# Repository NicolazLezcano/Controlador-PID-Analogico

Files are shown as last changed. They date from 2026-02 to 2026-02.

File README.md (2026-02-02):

# Controlador PID Analógico: Diseño, Simulación e Implementación

Este repositorio contiene el desarrollo integral de un controlador PID analógico, desde el modelado teórico y la simulación hasta el diseño de PCB y la validación en hardware real.
---

<p align="center">
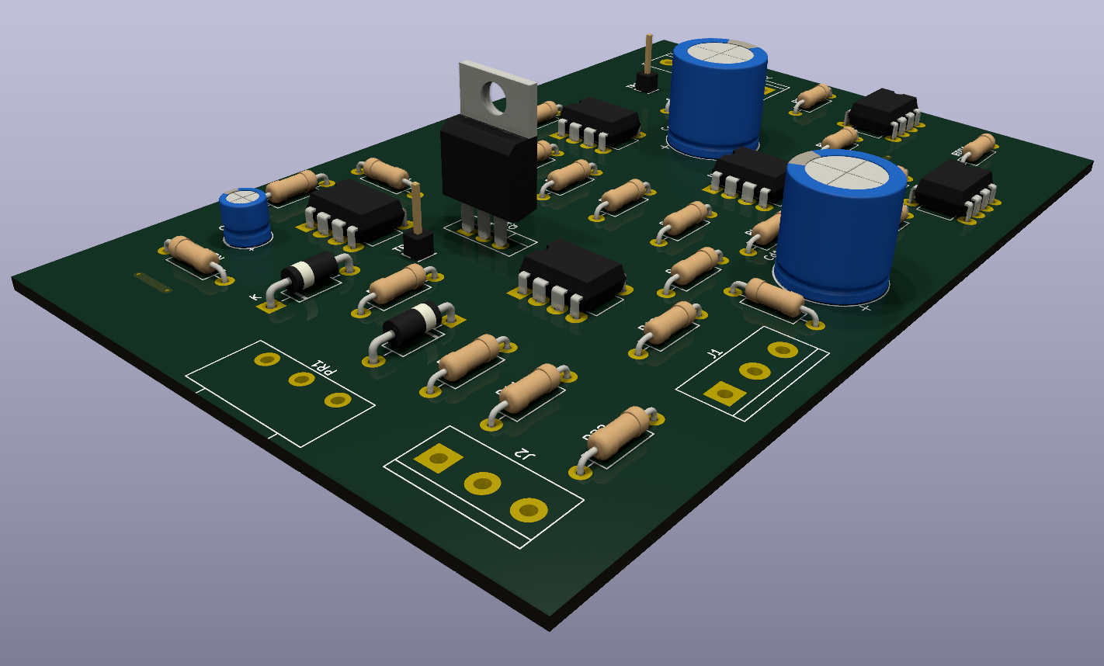
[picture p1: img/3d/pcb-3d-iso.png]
Hero Image
  
</p>

---

## 📋 Características Técnicas
* **Topología:** Controlador PID Analógico.
* **Software de Diseño:** KiCad (v9.0.7).
* **Simulación:** LTspice (v26.0.1).
* **Diseño de PCB:** Single-layer con plano de masa (GND).
* **Documentación:** Informe técnico completo incluido en la carpeta `/docs`.

---

## 📈 Simulación en LTspice
Antes del diseño físico, se validó la respuesta temporal del controlador utilizando **LTspice**. El objetivo fue ajustar las constantes para minimizar el *overshoot* y optimizar el tiempo de establecimiento ($t_s$).

$$u(t) = K_p e(t) + K_i \int_{0}^{t} e(\tau) d\tau + K_d \frac{de(t)}{dt}$$

| Controlador PID | Respuesta al Escalón |
| :---: | :---: |
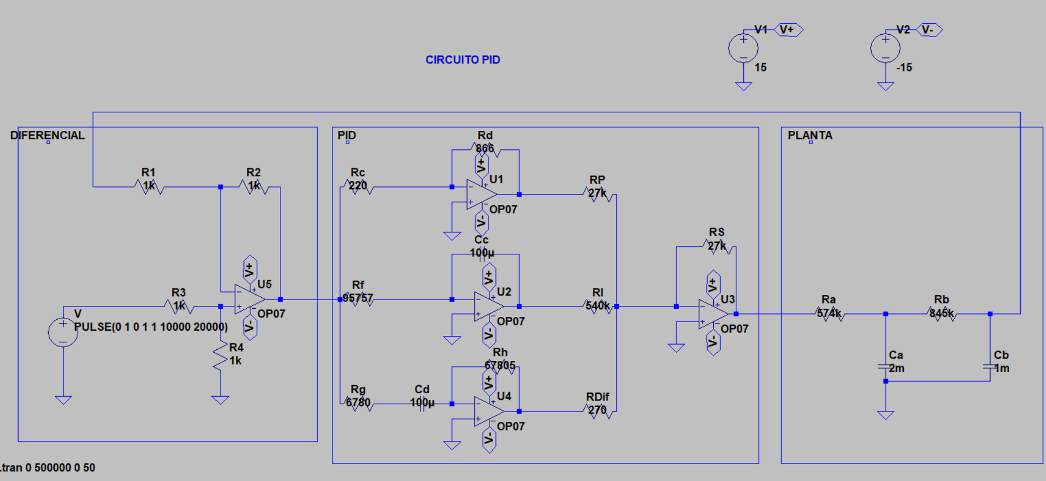
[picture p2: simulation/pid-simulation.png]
Circuito completo del Controlador PID
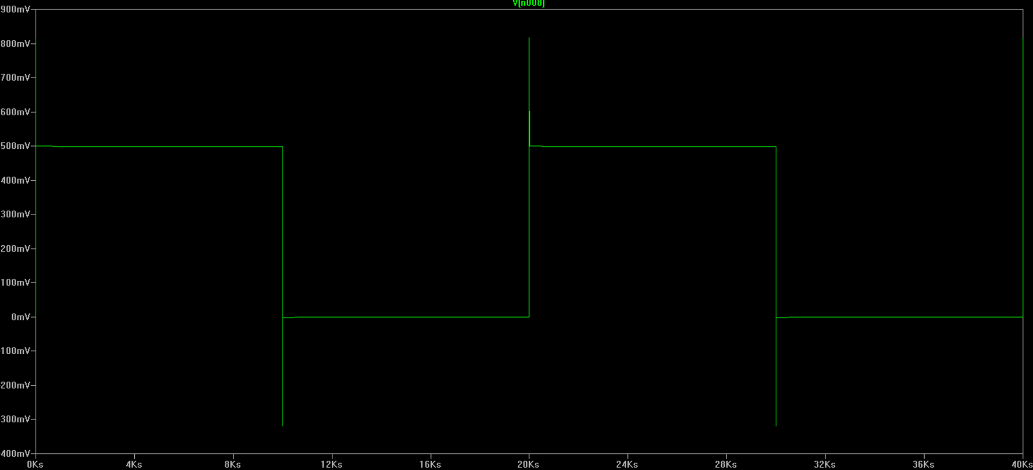
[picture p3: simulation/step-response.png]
Simulación de Respuesta al Escalón
|  |  |

> **Nota:** Los archivos de simulación (`.asc`) están disponibles en la carpeta `/simulation` para su replicación.

---

## 🎨 Diseño de Hardware (KiCad)
El diseño del PCB se optimizó para facilitar el prototipado rápido y garantizar la integridad de la señal frente a ruidos e interferencias.

### Esquemático (Hoja Raíz)
Se utilizó un diseño jerárquico para separar las etapas de adquisición, procesamiento de error y potencia.
<p align="center">
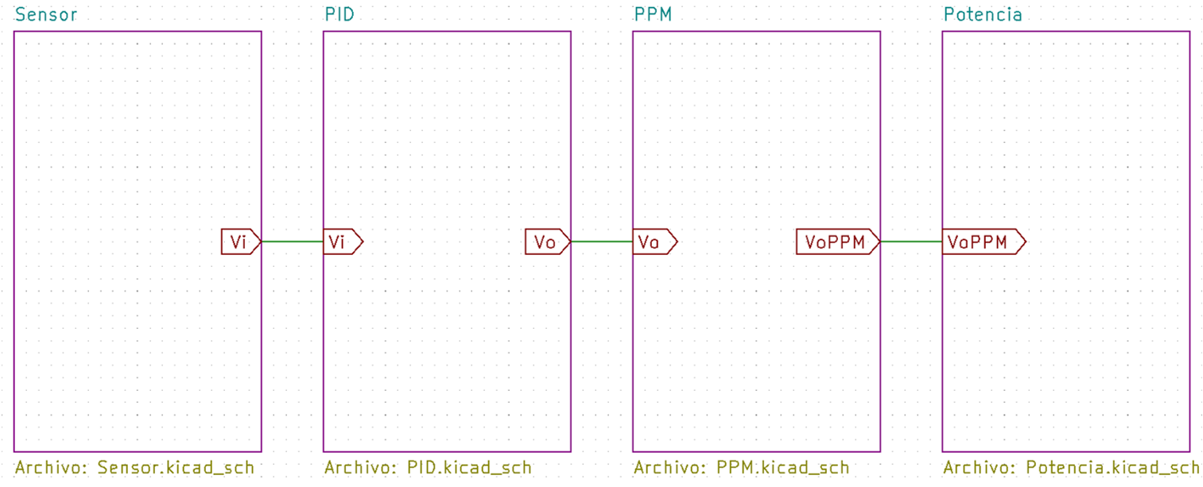
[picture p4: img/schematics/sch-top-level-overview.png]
Esquemático Root
  
</p>

| Sensor | PID |
| :---: | :---: |
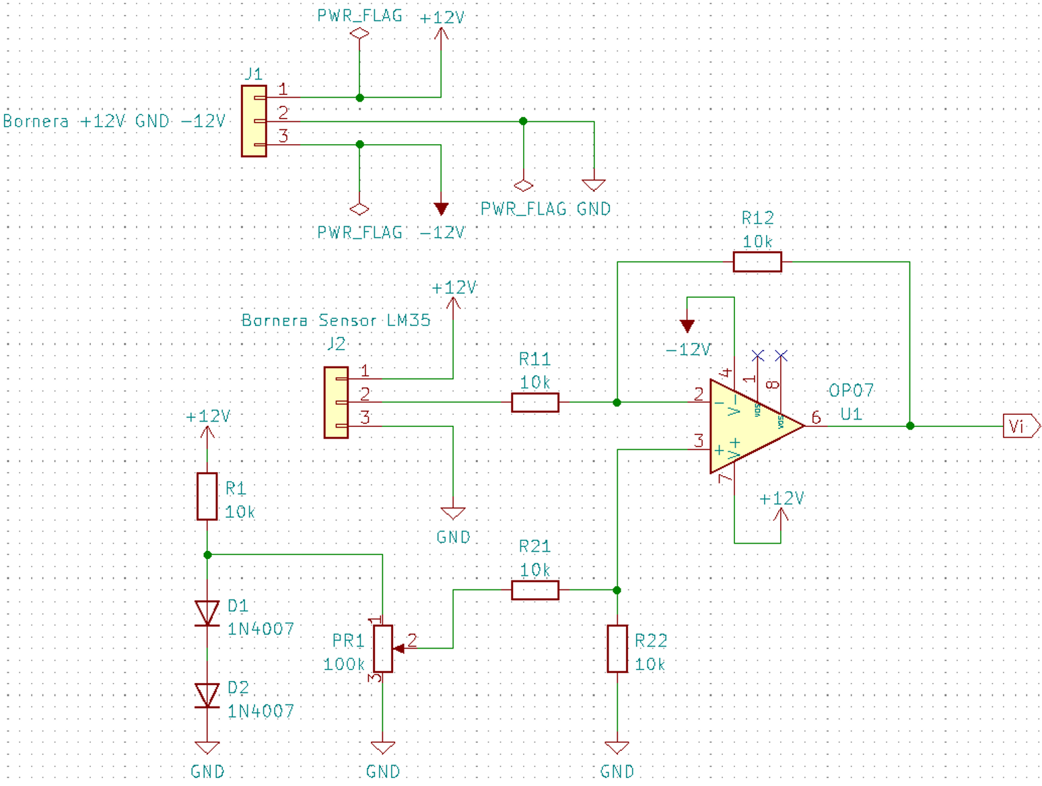
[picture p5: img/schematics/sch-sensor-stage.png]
Esquemático de la etapa de sensado
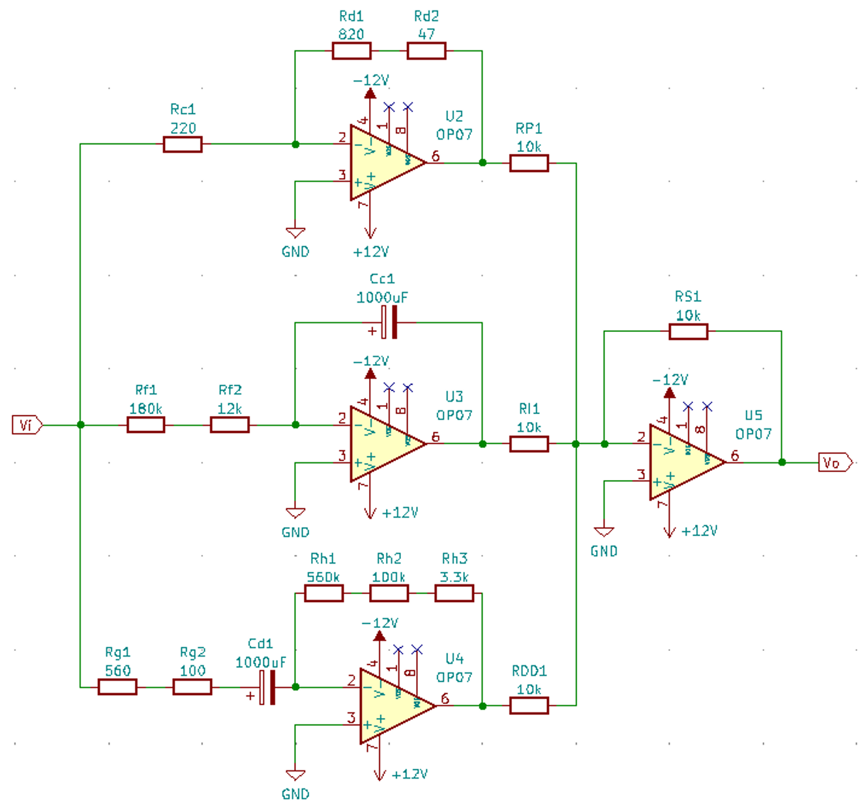
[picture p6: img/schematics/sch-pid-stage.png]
Esquemático del controlador PID
|  |  |

| PPM | Potencia |
| :---: | :---: |
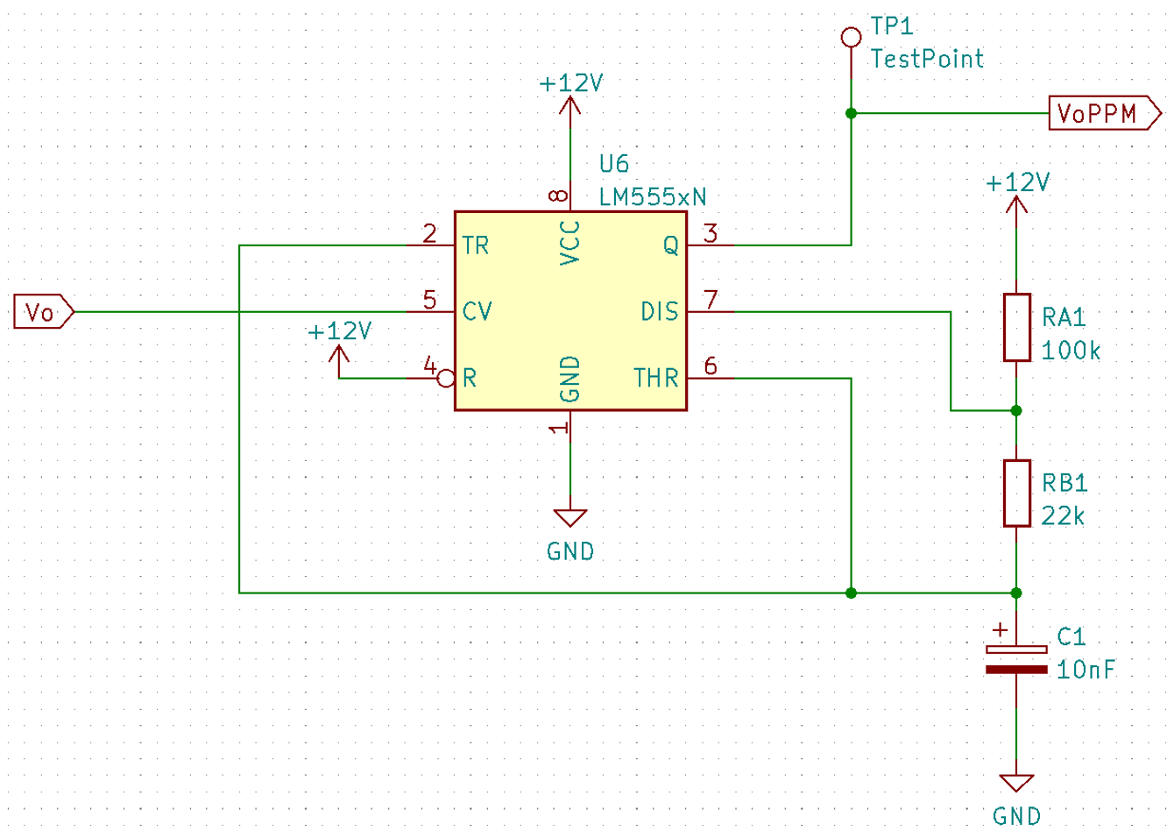
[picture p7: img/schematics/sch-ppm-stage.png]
Esquemático de la etapa PPM
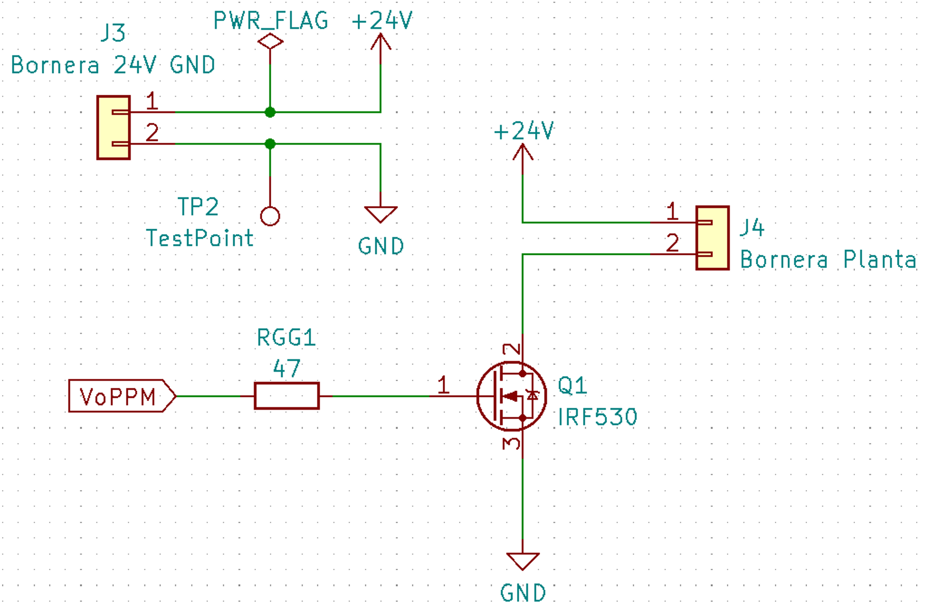
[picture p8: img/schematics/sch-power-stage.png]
Esquemático de la etapa de Potencia
|  |  |

### Layout y Ruteado
* **Integridad de Señal:** Se implementó un plano de masa (**Copper Pour**) para reducir la impedancia de retorno.
* **Single-Layer:** El ruteado se realizó exclusivamente en la capa inferior (**Back Copper**) para simplificar la manufactura manual.

| Ruteado de Pistas (Sin relleno) | Diseño Final (Con Plano de Masa) |
| :---: | :---: |
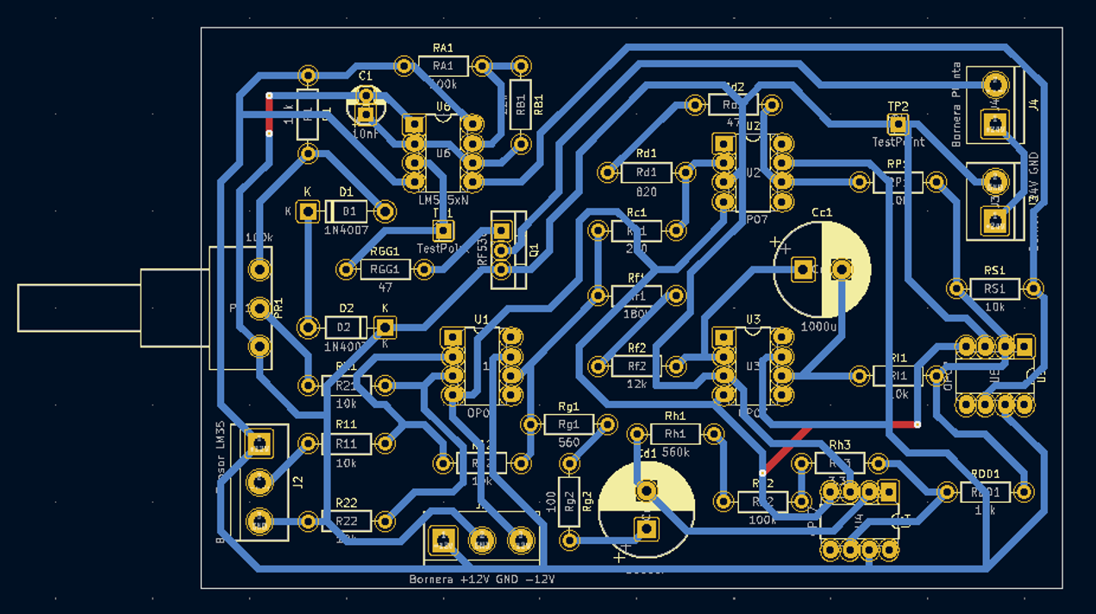
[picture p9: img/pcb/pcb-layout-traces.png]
Traces
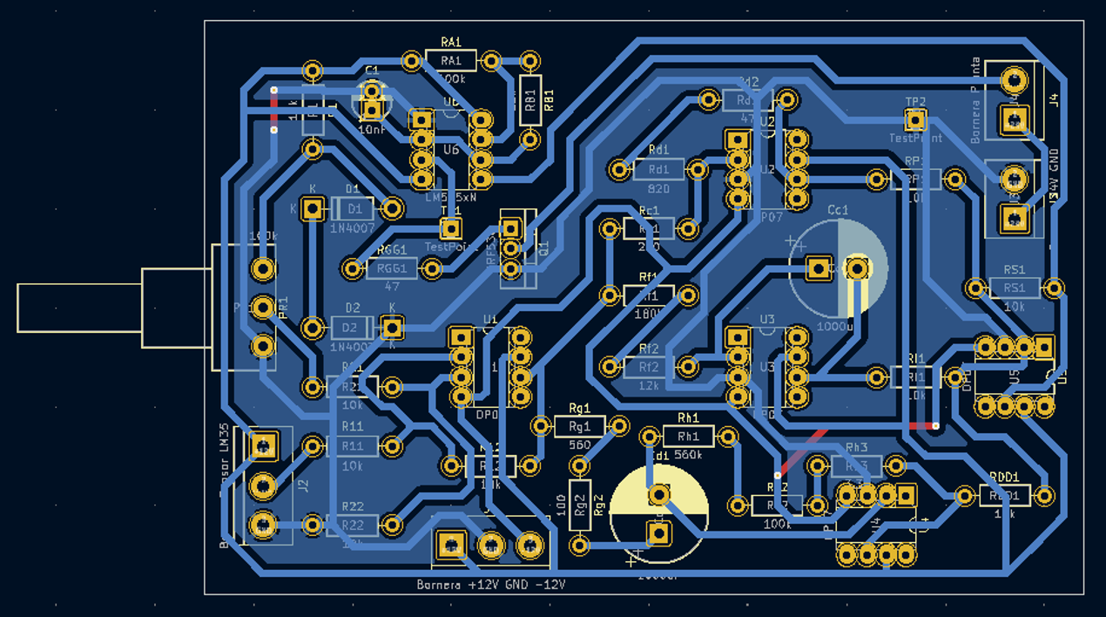
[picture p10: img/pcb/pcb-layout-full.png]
Full
|  |  |

| Modelo 3D (Vista Frontal) | Modelo 3D (Vista Posterior) |
| :---: | :---: |
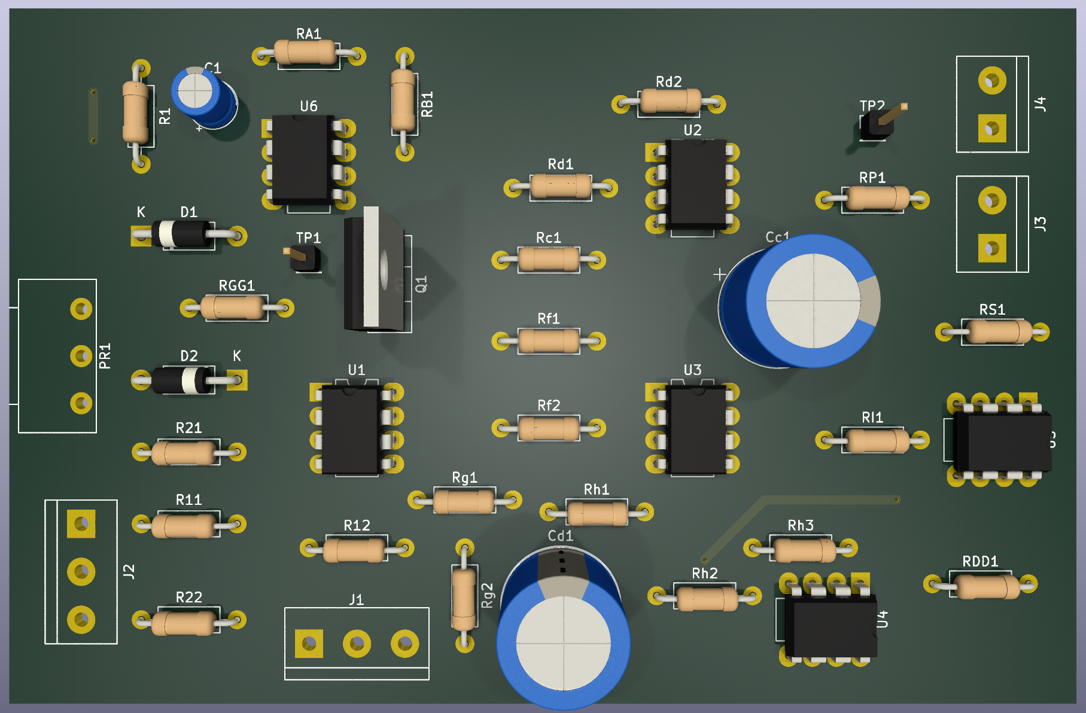
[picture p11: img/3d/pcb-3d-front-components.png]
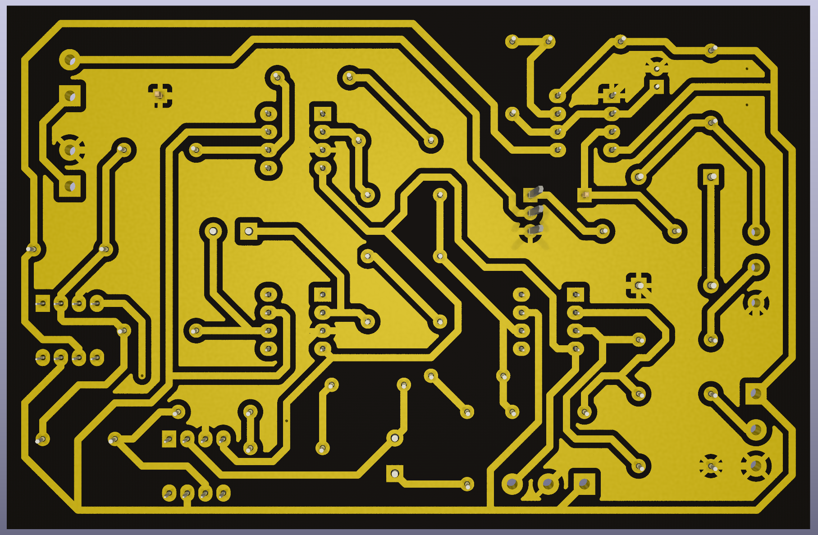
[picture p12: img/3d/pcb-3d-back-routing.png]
|  |  |

---

## 🛠️ Implementación y Resultados Reales
El proyecto concluyó con la fabricación física y la integración con el sensor y la carga, comparando los resultados experimentales con los simulados.

### Montaje y Calidad de Soldadura
| Vista Frontal (Componentes) | Vista Posterior (Soldadura) |
| :---: | :---: |
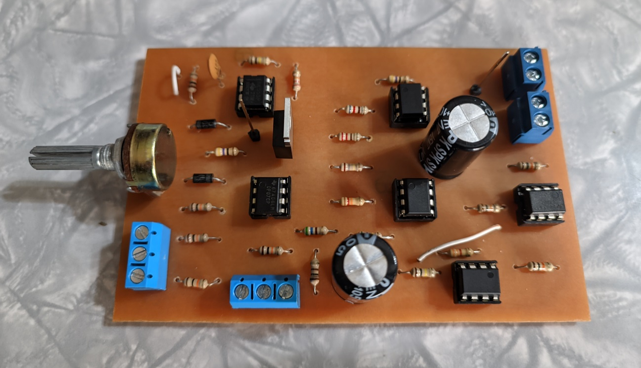
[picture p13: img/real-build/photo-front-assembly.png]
Front Photo
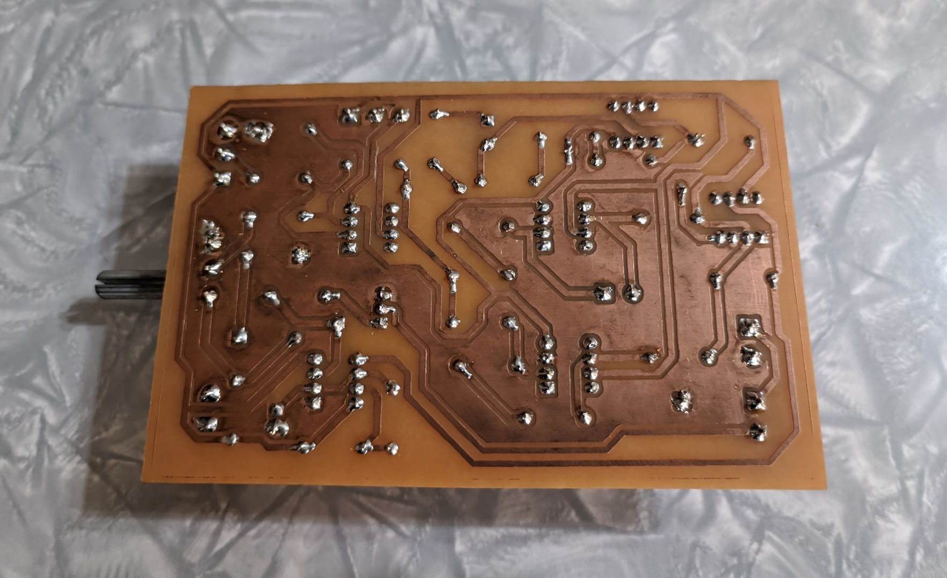
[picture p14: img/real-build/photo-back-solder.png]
Back Photo
|  |  |

### Integración del Sistema
Se validó el lazo cerrado conectando el controlador a la carga (planta térmica) y al sensor de temperatura LM35DZ, verificando la estabilidad del sistema ante perturbaciones.

<p align="center">
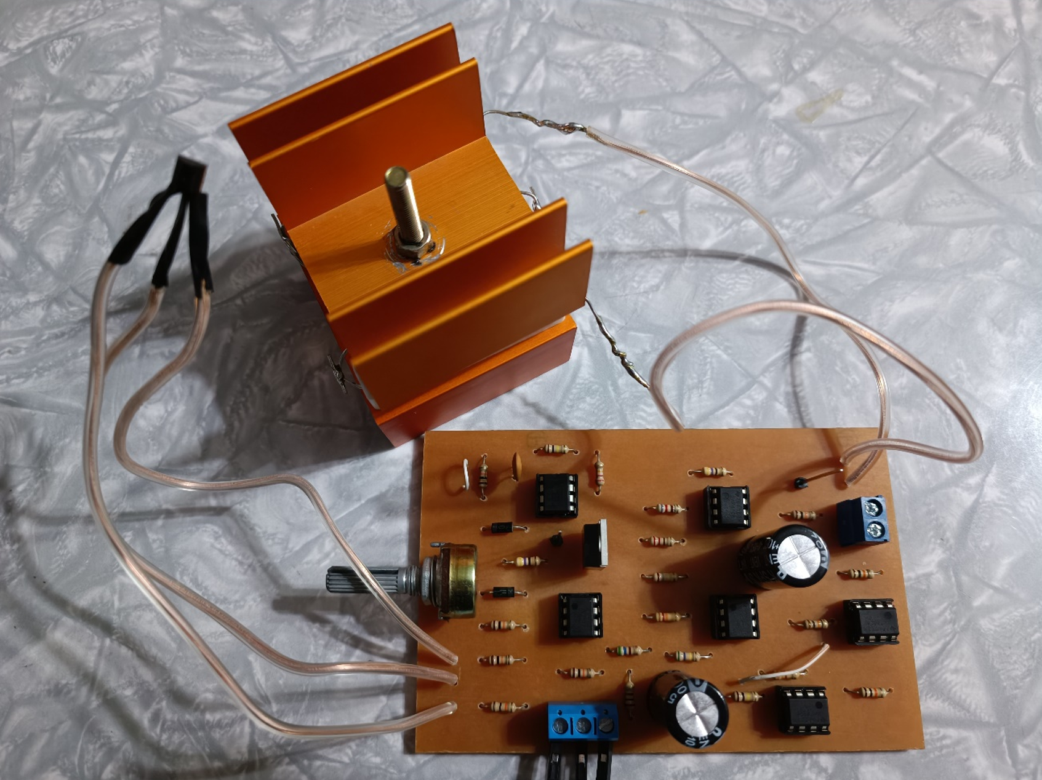
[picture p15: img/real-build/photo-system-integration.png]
Integración Final
  
</p>

---

## 📂 Estructura del Repositorio
* `/kicad`: Archivos fuente del proyecto (`.kicad_pro`, `.kicad_sch`, `.kicad_pcb`).
* `/simulation`: Archivos de LTspice y capturas de ondas.
* `/img`: Imágenes, renders y capturas utilizadas en este README.
* `/docs`: Informe técnico detallado y lista de materiales (BOM).
* `/manufacturing`: Documentación de manufactura dividida en capas (`gerbers/`) y perforaciones (`drill/`). Incluye un archivo .zip listo para servicios de prototipado rápido.

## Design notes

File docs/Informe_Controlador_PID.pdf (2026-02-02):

# Universidad Nacional de La Matanza

# Componentes e Instrumentos de Control

# Informe: Controlador PID

## Alumno: Lezcano Torres, Nicolaz Gastón

## Docentes: Ing. Marsilli, Fernando Roberto Ing. Gómez, Rodrigo Javier

## Código de asignatura: 1057

## Comisión: 01-3900

Componentes e Instrumentos de Control – Informe: Controlador PID

1

Índice:

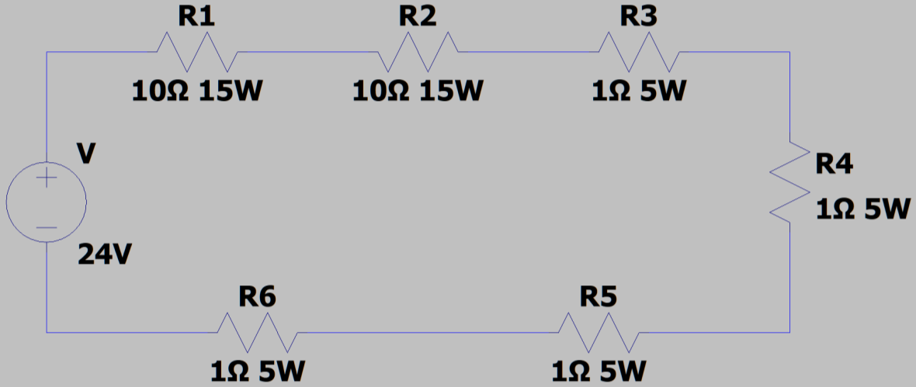
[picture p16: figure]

2

### 1. Planta Térmica

Se tiene una planta térmica, la cual se quiere controlar, la misma está conformada por un conjunto de resistores vinculados a una determinada disipación. Aquí la temperatura aumentará en función de la alimentación que reciban dichos resistores en su respectiva configuración. Además, la temperatura está relacionada a la potencia que genere la planta.

Requerimientos de la Planta: RTOTAL = 24Ω y PTOTAL = 24W =>

PTOTAL =

V

2

RTOTAL

=> V = √PTOTAL . RTOTAL = √24W . 24Ω => V = 24V

PTOTAL = V .I => I =

PTOTAL
V

=

24W
24V

=> I = 1A

Se utilizaron dos resistores cerámicos cementados de 10Ω 15W y cuatro resistores cerámicos cementados de 1Ω 5W, todo conectado en serie, dando como resultado una planta de 24ohm. Dado que la tensión máxima de alimentación es de 24V, circulará una corriente de 1A y la máxima potencia que obtendremos será de 24W.

Ilustración 1. Circuito de la planta térmica

RTOTAL = R1 + R2 + R3 + R4 + R5 + R6 = 10Ω + 10Ω + 1Ω + 1Ω + 1Ω + 1Ω =>

RTOTAL = 24Ω

PR1,2 = I

2
. R1,2 = 1A

2
. 10Ω => PR1,2 = 10W

PR3,4,5,6 = I

2
. R3,4,5,6 = 1A

2
. 1Ω => PR3,4,5,6 = 1W

PTOTAL = 2 . PR1,2 + 4 . PR3,4,5,6 = 2 . 10W + 4 . 1W => PTOTAL = 24W

Los dos disipadores son de aluminio y del tipo aletas, más en específico, son el modelo ZD-1. Los mismos fueron fijados por medio de un tornillo manteniendo firme el conjunto de resistencias y disipadores.

3

Ilustración 2. Planta térmica

Componentes:
x2 Resistor cerámico cementado 10Ω 15W
x4 Resistor cerámico cementado 1Ω 5W
x2 Disipador ZD-1 con una resistencia térmica: θ=3,5°C/W para 75mm x1 Tornillo y tuerca

### 1.1. Emulación de la Planta

En primer lugar, se alimentó la serie de resistencias para así elevar la temperatura de la planta hasta los 100°C. Luego se desconectó la alimentación y se realizó la medición del descenso de temperatura hasta la temperatura ambiente, de aproximadamente 25°C. La medición se realizó mediante un termómetro digital conectado a una PC, para de esta forma exportar la temperatura medida cada dos segundos.

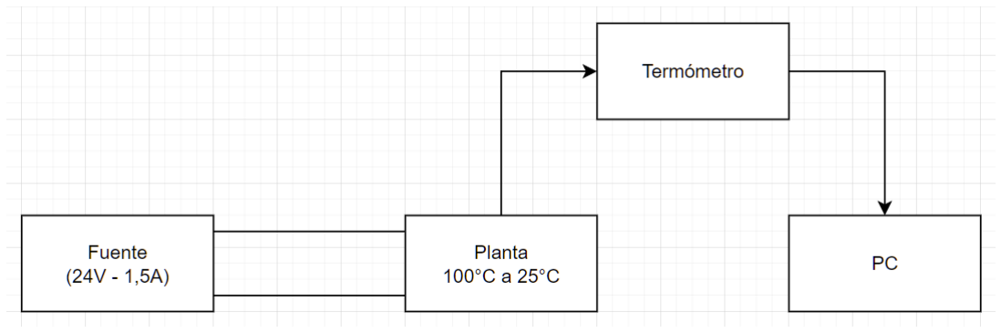
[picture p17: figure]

4

Ilustración 3. Diagrama de conexión para la medición de temperatura

Una planta de segundo orden se puede emular a partir de la siguiente respuesta de la curva, la cual es exponencial decreciente si se cumple que b<0 y d<0:

Curva(t) = a .e

b . t + c .e

d . t

A través de la utilización de MatLab se pueden calcular los coeficientes a, b, c y d. Los valores a ingresar en el software son la parte de la curva que decrece, es decir, cuando la temperatura disminuye a medida que aumenta el tiempo transcurrido, en este caso desde los 100°C hasta la temperatura ambiente, de unos 25°C.

Los exponentes b y d tienen que ser negativos, ya que de lo contrario se obtendría la suma de dos exponenciales crecientes, por lo tanto, se produciría una respuesta inestable. Dicho de otra manera, si los coeficientes b o d son positivos esto quiere decir que hay por lo menos un polo en el semiplano positivo (σ>0), lo que hace que el sistema sea inestable. En un principio, al calcular dichos exponentes se obtenía un valor de d positivo, lo cual es erróneo porque se genera un tipo de respuesta no deseada. Para solucionar este inconveniente se procedió a recortar la muestra por ambos extremos, se eliminaron valores repetidos y una de las acciones más importantes, se eliminaron partes de la muestra en donde la temperatura aumentaba con el paso del tiempo en vez de disminuir, ya que de lo contrario se agrega a la muestra una parte exponencial creciente que provoca la existencia de un valor de d positivo y la inestabilidad en la respuesta.

Las variables tiempo y temperatura, cuya muestra se tomó cada dos segundos, se ingresaron en MatLab como una matriz de 1 columna y 620 filas, ya que de otra forma el software no lo aceptaba.

Ilustración 4. Ingreso de datos en MatLab

Con MatLab se puede obtener el resultado de la suma de dos exponenciales. Estas exponenciales permiten emular una planta de segundo orden. La función a utilizar es la siguiente:

regresion = fit(tiempo,temperatura, ′exp2′)

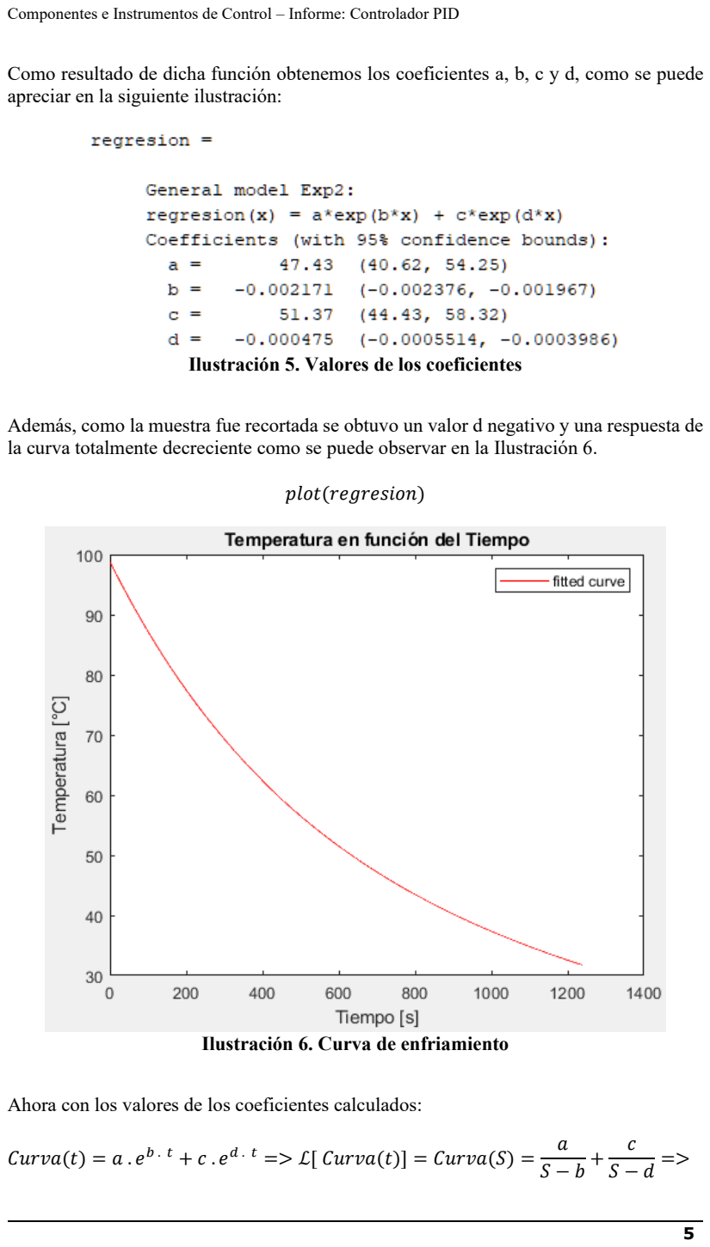
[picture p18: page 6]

5

Como resultado de dicha función obtenemos los coeficientes a, b, c y d, como se puede apreciar en la siguiente ilustración:

Ilustración 5. Valores de los coeficientes

Además, como la muestra fue recortada se obtuvo un valor d negativo y una respuesta de la curva totalmente decreciente como se puede observar en la Ilustración 6.

plot(regresion)

Ilustración 6. Curva de enfriamiento

Ahora con los valores de los coeficientes calculados:

Curva(t) = a .e

b . t + c .e

d . t => ℒ[ Curva(t)] = Curva(S) =

a
S − b

+

c
S − d

=>

6

Curva(S) =

a . (S − d) + c . (S − b)
(S − b) . (S − d)

2 Polos reales negativos: p1 = b y p2 = d => Respuesta Sobreamortiguada

Como |d| = 0,000475 << |b| = 0,002171 => d es el polo dominante

El tiempo de establecimiento se puede calcular a partir del polo dominate de la planta:

Tiempo de Establecimineto: te = 4 . τ = 4 .

1
|d|

=

4
0,000475 => te = 8421,053 s

De los coeficientes calculados nos interesa los polos obtenidos, entonces se puede plantear la siguiente planta genérica de segundo orden para obtener la función transferencia:

G(S) =

k
(S − b) . (S − d)

=

k
S

2 + (−b − d) . S + b . d

Reemplazando por b=-0,002171 y d=-0,000475:

G(S) =

k
S

2 + 2,646 . 10⁻³. S + 1,031 . 10⁻⁶ =>

G(S) =

k
1
S

2 + 2,646 . 10⁻³. S + 1,031 . 10⁻⁶

1
1,031 . 10⁻⁶
1
1,031 . 10⁻⁶

=>

G(S) =

k
1,031 . 10⁻⁶
0,97 . 10⁶ . S

2 + 2566,44 . S + 1

Como k′ =

k
1,031 . 10⁻⁶ => G(S) =

k′
0,97 . 10⁶ . S

2 + 2566,44 . S + 1

Sí k′ = 1 => G(S) =

1
0, 97 . 106 . S

2 + 2566, 44 . S + 1

(1)

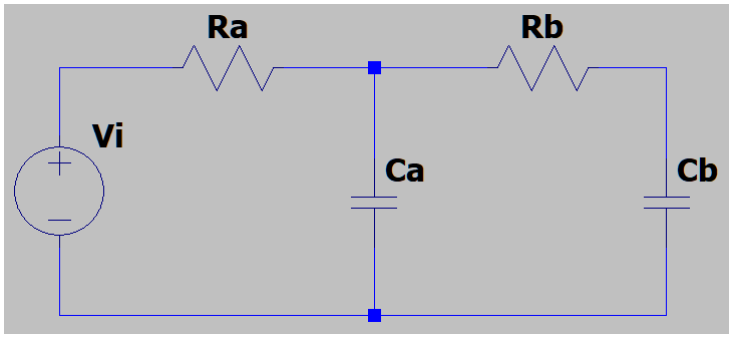
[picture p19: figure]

7

### 1.2. Simulación de la Planta

Ilustración 7. Planta G(S) simulada

Cálculo de G(S) mediante el Método Sistemático de Mallas:

G(S) =

VO(S)
Vi(S)

=

VCb(S)
Vi(S)

=

I2(S) .

1
S . Cb
Vi(S)

I2(S) =

ΔI2
ΔZ =
Ra +

1
S . Ca

Vi(S)

−

1
S . Ca

0

Ra +

1
S . Ca

−

1
S . Ca

−

1
S . Ca

Rb +

1
S . Ca

+

1
S . Cb

=>

I2(S) =

Vi(S)
S . Ca
(Ra +

1
S . Ca

) . (Rb +

1
S . Ca

+

1
S . Cb

) − (−

1
S . Ca

) . (−

1
S . Ca

)

=>

I2(S) =

Vi(S)

Ra . Rb . Ca . S + Ra + Rb +

Ra . Ca
Cb

+

1
S . Cb

G(S) =

I2(S)
S . Cb . Vi(S)

=

1
S . Cb . Vi(S)

Vi(S)

Ra . Rb . Ca . S + Ra + Rb +

Ra . Ca
Cb

+

1
S . Cb

8

G(S) =

1
Ra .Rb . Ca . Cb . S

2 + (Ra . Cb + Rb .Cb + Ra . Ca ) . S + 1

(2)

Para obtener los valores de los resistores y capacitores de la simulación igualo (1) con (2):

(1) = (2) => G(S) =

1
0,97 . 10⁶ . S

2 + 2566,44 . S + 1

=

=

1
Ra . Rb . Ca . Cb . S

2 + (Ra . Cb + Rb . Cb + Ra . Ca ) . S + 1

Como tienen el mismo numerador puedo igualar los coeficientes del denominador de ambos miembros:

0,97 . 10⁶ = Ra . Rb . Ca . Cb | (3)
2566,44 = Ra . Cb + Rb . Cb + Ra . Ca | (4)

Reescribiendo la ecuación (3):

Rb =

0,97 . 10⁶
Ra . Ca . Cb

Reemplazando (3) en (4) obtengo la siguiente ecuación cuadrática:

(Ca + Cb

) . Ra

2 − 2566,44 . Ra +

0,97 . 10⁶
Ca

= 0

En primer lugar, se estableció que: Ca = 2mF = 2000uF y Cb = 1mF = 1000uF

Con dichos valores se obtuvo de la ecuación cuadrática: Ra1 = 573,667kΩ y

Ra2 = 281,812kΩ

Reemplazando los anteriores valores de resistencia en la ecuación (3) se obtuvo que:

Rb1 = 845,428kΩ y Rb2 = 1,721MΩ

Se eligió el primer juego de valores, por lo tanto: Ra = Ra1 y Rb = Rb1

Además, se aproximaron dichos valores de resistencia.

9

Los valores de los resistores y los capacitores son los siguientes:

Ra = 574kΩ ; Ca = 2mF = 2000uF

Rb = 845kΩ ; Cb = 1mF = 1000uF

Por último, se recalculó la función transferencia de la planta G(S) utilizando los valores obtenidos y la ecuación (2), dando como resultado:

G(S) =

1
970060 . S

2 + 2567 . S + 1

### 2. Controlador PID Analógico

Para poder controlar la temperatura de la planta, se ha diseñado un controlador PID que obtiene la señal de referencia de un potenciómetro integrado en el circuito, realimentado negativamente por un sensor de temperatura LM35. Las resistencias de la planta harán de actuadores, dado que, al provocar una circulación de corriente, la temperatura aumentará por efecto Joule.

### 2.1. Modelo de la Planta

Para el modelizado, se consideró a la planta como un sistema de segundo orden, siendo la función de transferencia de la siguiente forma:

G(S) =

1
A . S

2 + B . S + 1

Mediante la curva de enfriamiento se obtuvieron los parámetros A y B, y se llegó a la siguiente expresión de la función transferencia de la planta:

G(S) =

1
970000 . S

2 + 2567 . S + 1

A partir de la planta sin realimentación, podemos evaluar su respuesta ante una señal escalón unitario, para de esta forma ver sus características sin un controlador:

Ilustración 8. Diagrama en bloques del sistema

10

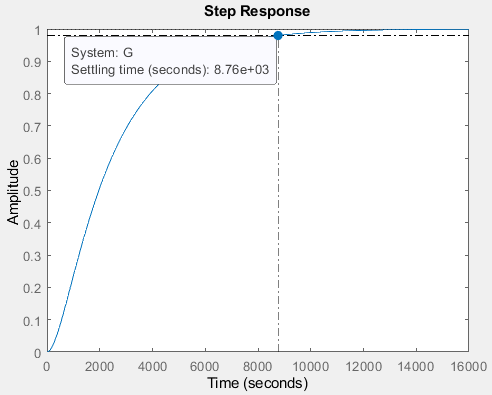
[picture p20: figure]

Ilustración 9. Respuesta al escalón unitario

De la respuesta al escalón unitario de la planta G(S), se obtuvo:

Tiempo de establecimiento: te = 8760 s

### 2.2. Requerimientos de la Respuesta Dinámica

Conociendo los valores de la respuesta sin controlador, se pretende mejorar dichas características, por lo tanto, se establecieron los siguientes requerimientos:

Tiempo de establecimiento: te

′ ≤ 0,75 .te = 0,75 . 8760 s => te

′ ≤ 6570 s

OverSℎoot o Sobreimpulso: MP ≤ 30%

### 2.2.1. Diseño del Controlador PID

Mediante la herramienta SisoTool de MatLab, se procedió a diseñar el controlador. En primer lugar, se cargó la función transferencia y se establecieron los parámetros de la respuesta dinámica requerida. Con esto el sistema nos devuelve una gráfica que nos muestra el lugar de las raíces a lazo cerrado y nos marca automáticamente en el plano complejo la zona donde deben estar ubicados los polos dominantes del sistema para cumplir con los requisitos cargados.

11

El diseño del compensador se realizará a partir del siguiente diagrama, en donde el controlador PID es el bloque C, la planta térmica es el bloque G y la realimentación negativa unitaria es el bloque H:

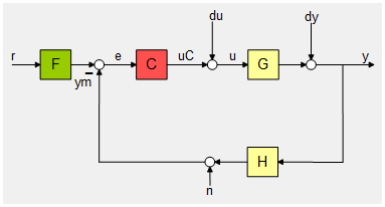
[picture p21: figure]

Ilustración 10. Diagrama en bloques del sistema realimentado

Hecho esto, se agregan los polos y los ceros que le corresponden al controlador PID. Mediante SisoTool podemos visualizar la respuesta al escalón unitario del sistema y al mismo tiempo modificar el Root Locus, para de esta forma probando diferentes alternativas tratar de llegar al objetivo.

En primer lugar, se establecieron los siguientes polos y ceros para el controlador PID, uno de los polos se ubica en el origen ya que cumple la función de ser integrador, además, se utiliza una k=1:

Ilustración 11. Primer ingreso de polos y ceros del controlador

Posteriormente, el polo en el origen se mantiene en el mismo lugar y se acercan los ceros y los polos hacia el origen hasta que los polos dominantes, de color rojo, se encuentren en la zona deseada. Luego de ir probando y moviendo el Root Locus, llegamos a una posición en la que estos se encuentran en la intersección entre la línea vertical correspondiente al tiempo de establecimiento del sistema y las diagonales, correspondientes al OverShoot.

12

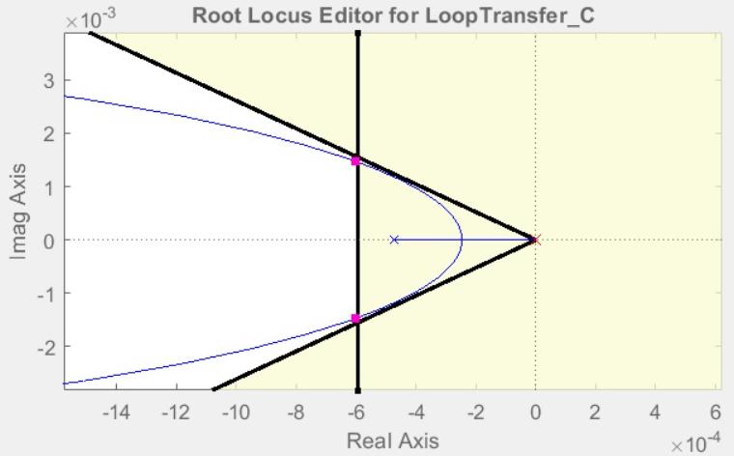
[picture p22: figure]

Ilustración 12. Root Locus de la planta con el controlador y H=1

Finalmente, con esta ubicación de singularidades, podemos ver la respuesta temporal a un escalón del sistema realimentado y con el controlador, verificando que cumpla las especificaciones:

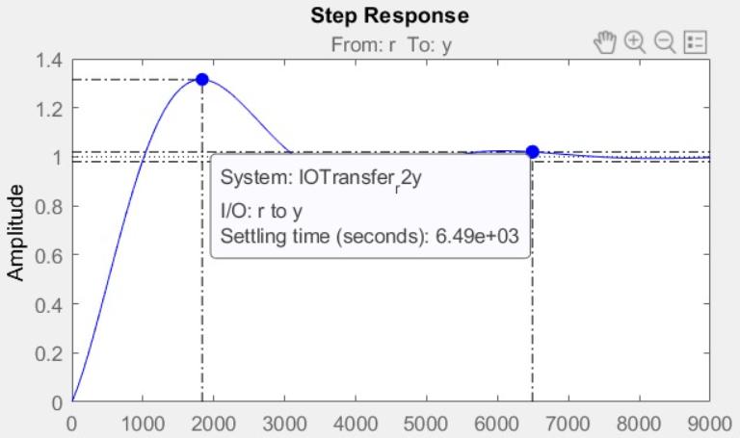
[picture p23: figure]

Ilustración 13. Tiempo de establecimiento de la planta con el controlador y H=1

En este caso se verifica que se cumple con el tiempo de establecimiento estipulado:

te

′ = 6490 s < 6570 s

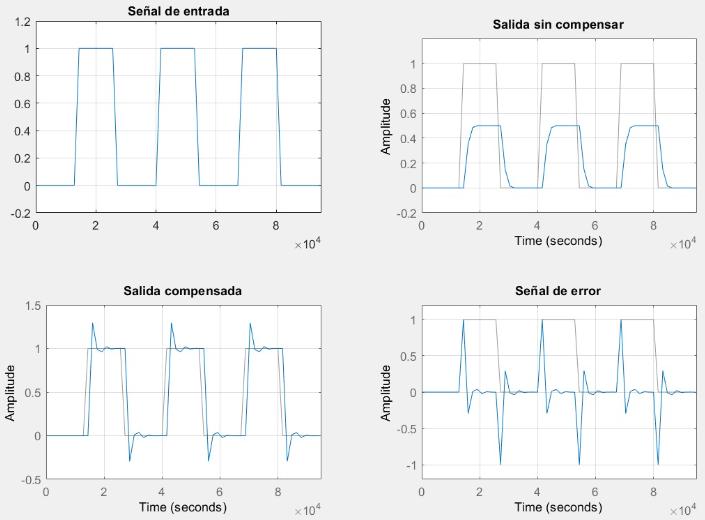
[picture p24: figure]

13

Además, podemos ver frente a una señal cuadrada cómo se comporta el sistema:

Ilustración 14. Señales de entrada, salida y error

La función de transferencia del controlador obtenido mediante SisoTool, es la siguiente:

C(S) =

998,9 . (S + 0,002) . (S + 0,00392) S . (S + 1,5)

=>

C(S) =

998,9 . S

2 + 5,913 . S + 0,007832
S . (S + 1,5)

(5)

### 2.2.1.1. Componentes del Controlador PID

Tenemos que la transferencia del controlador está dada por:

C(s) =

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
2 + (

Rd
RcRgCd

+

1
RfCc

) S +

1
RfRgCcCd
S (S +

1
RgCd

)

(6)

Donde ponemos reescribirla de la siguiente manera:

C(s) =

VO
VI

=

aS

2 + bS + c
S(S + d)

(7)

14

Si a los usamos los resultados obtenidos de Matlab, en la ecuación (5), y los combinamos con la ecuación (6) y (7) nos queda:

Rd
Rc

+

Rℎ
Rg

= a = 998,9 (8)

Rd
RcRgCd

+

1
RfCc

= b = 5,913 (9)

1
RfRgCcCd

= c = 0,007832 (10)

1
RgCd

= d = 1,5 (11)

Además, podemos mostrar la ganancia de cada etapa del controlador:

Vo
Vi

(P) = −

Rd
Rc

= −P (12) Etapa proporcional

Vo
Vi

(I) = −

1
RfCC. S

= −

I
S
(13) Etapa integral

Vo
Vi

(D) = −

Rℎ
Rg

. S

1
RgCd

+ S

= −

D. S
pd + S
(14) Etapa derivativa

Nos quedan, entonces, estas ganancias expresadas de la siguiente manera:

I =

c
d

= 0,0052213 (15)

P =

b − I
d

= 3,9385 (16)

D = a − P = 994,9615 (17)

Si usamos estos valores de ganancias y los reemplazamos en las ecuaciones (8), (9), (10) y (11) vamos a obtener valores de componentes muy elevados, obteniendo los siguientes:

Proporcional: Rc = 220Ω Rd = 866Ω

Integral: Rf = 191,52KΩ Cc = 1mF

Derivativo: Rg = 666, 67Ω | Rℎ = 663,31KΩ | Cd = 1mF

15

Utilizando los valores comerciales más próximos nos quedan los siguientes valores de componentes:

Proporcional: Rc = 220Ω y Rd = 820Ω + 47Ω

Integral: Rf = 180kΩ + 12kΩ y Cc = 1000uF

Derivativo: Rg = 560Ω + 100Ω , Rh = 560kΩ + 100kΩ + 3, 3kΩ y Cd = 1000uF

Sumador: RS = RP = RI = RD = 10kΩ

Dado que los valores de los capacitores y de Rh son algo difíciles de conseguir, se usará el sumador para, modificando la ganancia de cada etapa, equilibremos esa modificación y obtengamos valores de componentes más accesibles.

De esta forma, la función de transferencia del PID más el sumador nos queda:

− (−

P. Vi
RP

−

I. Vi
S. RI

−

D. S. Vi
(S + pd

)RD

)Rs = Vo

Vo
Vi = (

P
RP

+

I
S. RI

+

D. S
(S + pd

)RD

) RS

Vo
Vi =

P. RS
RP

+

I. RS
S. RI

+

D. RS

. S
(S + pd

)RD

(18)

El valor de P no es un problema, solo se encarga de establecer el valor de Rd y no tenemos un problema allí. Por eso necesitamos modificar las ganancias I y D a valores más convenientes, aumentado el primero y reduciendo el segundo.

Siendo I

∗ y D

∗
los nuevos valores de I y D

I

∗ = I. kI | D

∗ =

D
kD

La transferencia (18) nos queda de la siguiente manera:

Vo
Vi =

P. RS
RP

+

I

∗
. RS
S. RI

+

D

∗
| . RS

. S
| (S + pd

)RD

(19)

Para que la transferencia obtenida con SisoTool no sea modificada necesitamos cumplir:

P. RS
RP

= α. P

I

∗
. RS
RI

= α.I = α

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
. RS
(S + pd

)RD

= α

D
(S + pd

)

= α

D

∗kD
(S + pd

)

→

RS
RD

= α. kD

De aquí, tenemos que α es la ganancia del sumador y vamos a imponerla como “1”. Continuando, vamos a elegir kI y kD según el siguiente criterio:

kI = 20 | kD = 99 → I

∗ = 0,10443 y D

∗ = 10

Teniendo en cuenta estos valores y reemplazando por I

∗donde tenemos I y D

∗ donde
tenemos D, tenemos que:

I

∗ =

c
d
| =
| 1 RfCc → Rf =

1
I

∗Cc

(20)

P

∗ = P =

b − I

∗
d

=

Rd
Rc

→ Rd = P

∗
. Rc (21)

D

∗ = a − P

∗ =

Rℎ
Rg

→ Rℎ = D

∗
. Rg (22)

b =

Rd
RcRgCd

+

1
RfCc

→ Rg =

Rd
RcCd

RfCc
b. RfCc − 1

(23)

Finalmente, fijando los valores de Cc

, Cd y Rc obtenemos los siguientes resultados:

Proporcional: Rc = 220Ω Rd = 866Ω

Integral: Rf = 95,75kΩ Cc = 100μF

Derivativo: Rg = 6,78kΩ | Rℎ = 67,805kΩ | Cd = 100μF
Sumador: RP = RS = 27kΩ RI = 540kΩ | RD = 270Ω

Utilizando los valores comerciales más próximos nos quedan los siguientes valores de componentes:

Proporcional: Rc = 220Ω y Rd = 820Ω + 47Ω

Integral: Rf = 68kΩ + 27kΩ y Cc = 100μF

Derivativo: Rg = 6, 8 kΩ , Rh = 68kΩ y Cd = 100μF

Sumador: RP = RS = 27kΩ , RI = 180kΩ + 180kΩ + 180kΩ y RD = 270Ω

17

Donde el circuito a aplicar es:

Ilustración 15. Controlador PID modificado

### 3. Etapa de Entrada

Esta etapa del circuito es la encargada de fijar la señal de referencia, medir la señal que se recibe del sensor de temperatura y restar esta última a la primera, obtenido al final la señal de error que será la utilizada como señal de entrada del controlador PID.

e = Tr − Tm

Donde Tr es la señal de referencia y Tm la señal medida.

Les etapa está dada por:

18

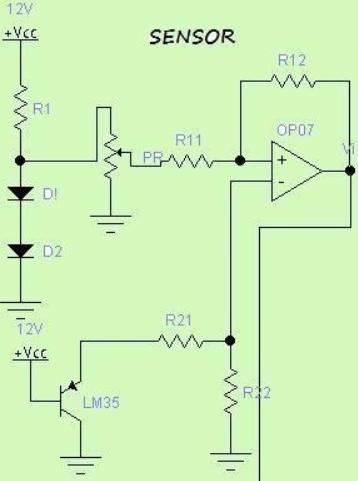
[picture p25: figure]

Ilustración 16. Circuito de sensado

Aquí tenemos que saber que el operacional está funcionando como un restador y R11, R12, R21 y R22 deben ser iguales para cumplir esta función. Los diodos se están encargando de establecer la tensión de entrada al potenciómetro PR.

Dado que vamos a estar usando un LM35 que nos proporcional 10mV/°C y queremos establecer nuestro SetPoint en 100°C, la tensión máxima que nos estará entregando el sensor es de 1V.

Si usamos un potenciómetro de 100k y llamamos Va a la tensión impuesta por los dos diodos y Vb a la tensión que queremos usar de SetPoint (1V), la configuración del potenciómetro tendrá que ser la siguiente:

Ilustración 17. Configuración del potenciómetro

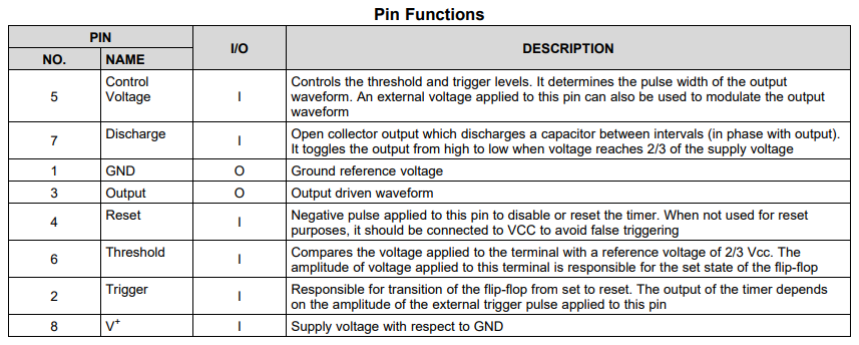
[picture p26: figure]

19

### 4. Etapa PPM y de Potencia

La etapa de potencia consta solamente de un transistor MOSFET, el cual conmutará la alimentación de la serie de resistencias de la planta.

La señal de accionamiento del MOSFET proviene de un modulador de posición de pulso (PPM) que tiene por objetivo variar el tiempo de accionamiento de las resistencias en función de la señal de entrada VO_PID, proveniente de la salida de la etapa PID. El modulador está construido a partir del integrado LM555 configura en modo astable. De esta forma la señal de salida del integrado será un pulso positivo de ancho fijo y amplitud VCC, que, en función de la señal de entrada, se repetirá más o menos seguido.

Del DataSheet necesitamos obtener el tipo de configuración astable:

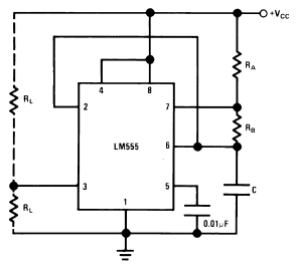
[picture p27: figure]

Ilustración 18. LM555 en modo astable

Y además el nombre de los pines con su descripción:

Ilustración 19. Funciones de los pines del LM555

20

### 4.1. Diseño de la Etapa PPM

La condición de diseño para el oscilador en modo astable es la siguiente:

f = 1kHz

Valiéndonos de las fórmulas que nos brinda la hoja de datos se procederá a calcular los componentes de dicho oscilador:

f =

1,44
(RA + 2 . RB) . C

=> RB =

1,44 − f . RA . C
2 . f . C

(24)

Se establece que: RA = 1kΩ y C = 1μF

Luego, se reemplazan los valores anteriores en la ecuación (24):

RB =

1,44 − 1kHz . 1kΩ . 1μF
2 . 1kHz . 1μF

=> RB = 220Ω

Los valores de componentes para el PPM son:

RA = 1kΩ , RB = 220Ω y C = 1μF

En las especificaciones del LM555 se recomienda que se cumplan las siguientes condiciones:

RA > 5kΩ y RB > 3kΩ

Por lo mencionado anteriormente se procedió a multiplicar por cien los resistores y a dividir por cien a la capacidad, ya que esto no altera la condición de frecuencia solicitada, quedando:

RA = 100kΩ , RB = 22kΩ y C = 10nF

Una vez calculados los valores de los elementos se pueden obtener las características de la forma de onda de salida del PPM:

21

Ilustración 20. Forma de onda del oscilador en modo astable

En este caso como la alimentación de la etapa PPM es de VCC=12V, la amplitud de la señal cuadrada de salida también es de 12V. En la Ilustración 20, en el gráfico de abajo, se puede observar la carga y descarga del capacitor C y los tiempos asociados a dichos procesos.

Amplitud:

A = VCC => A = VOUT = 12V

Tiempo de carga:

t1 = 0,693 . (RA + RB) . C = 0,693 . (100kΩ + 22kΩ) . 10nF => t1 = 0,84546 ms

Tiempo de descarga:

t2 = 0,693 . RB . C = 0,693 . 22kΩ . 10nF => t2 = 0,15246 ms

Período:

T = t1 + t2 = 0,84546 ms + 0,15246 ms => T = 997,92 ms ~1ms

Ciclo de actividad (Duty Cycle):

D =

RA + RB
RA + 2 . RB

=

100kΩ + 22kΩ
100kΩ + 2 . 22kΩ => D = 0,847 = 84,7%

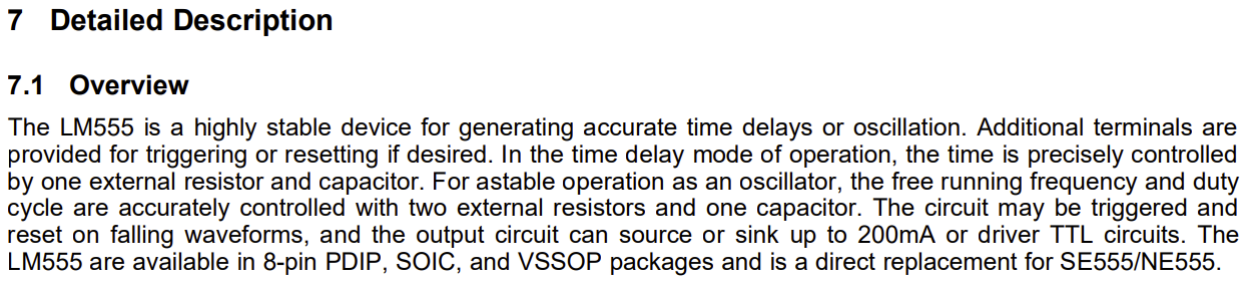
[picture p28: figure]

22

D =

TON

TOFF + TON

=

t1
t2 + t1

=

0,84546 ms
0,15246 ms + 0,84546 ms

=> D = 0,847 = 84,7%

Corroboración de que los valores de componentes obtenidos son correctos:

f =

1
T

=

1
997,92 ms

=> f = 1,0021kHz => f = 1kHz

Por último, una característica muy importante, que hay que tener en cuenta es la corriente de salida del LM555.

Ilustración 21. Corriente de salida del LM555

En el apartado 7.1 de la hoja de datos del LM555 se especifica que la corriente máxima es de 200mA.

IOUT MAX = 200mA

### 4.2. Diseño de la Etapa de Potencia

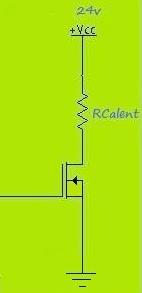
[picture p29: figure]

Ilustración 22. Circuito de la etapa de potencia

El resistor RCalent representa a la planta térmica de 24Ω. A la hora de elegir un transistor MOSFET hay que tener en cuenta algunas condiciones de diseño. La primera es la tensión

23

de ruptura del mismo y la segunda es que la tensión que ingresa al terminal Gate (G) tiene que ser mayor a la tensión VT = VGS(TH)
, que es la diferencia de potencial a partir de la cual el dispositivo empieza a conducir corriente (ID) con una transferencia parabólica.

Se eligió el transistor MOSFET tipo N de canal inducido IRF 530 por la disponibilidad que tiene en el mercado y porque cumple con los requisitos necesarios para ser utilizado en la etapa de potencia. A continuación, se verificará que cumple con las condiciones de diseño.

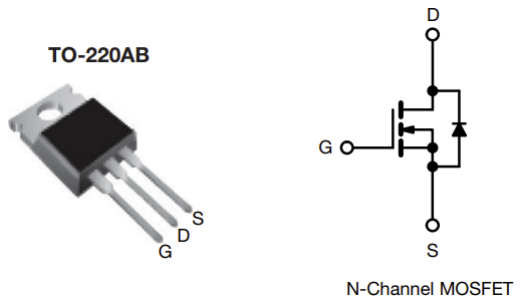
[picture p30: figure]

Ilustración 23. IRF 530 de Vishay

De la hoja de datos del IRF 530 de la marca Fairchild se puede obtener la máxima tensión de operación entre Drain (D) y Source (S) y la tensión a superar para que el MOSFET empiece a conducir:

Ilustración 24. Parámetros del IRF 530 de Fairchild

De la tabla anterior se obtiene que: BVDSS = 100V y VGS(tℎ) = 4V

La etapa de potencia se alimenta con una tensión VCC=24V y al terminal G (gate) del MOSFET le llega una tensión VGS = 12V cuando la salida del LM555 en modo astable de la etapa PPM se encuentra en estado alto, con dichos datos se procederá a confirmar que el IRF 530 cumple los requerimientos necesarios.

Relacionado con la tensión de ruptura del MOSFET se tiene que cumplir que:

VCC ≤ 0,75 . BVDSS = 0,75 . 100V = 75V => VCC ≤ 75V

Se cumple que:
VCC = 24V ≪ 75V

Para que el MOSFET entre en modo de conducción se tiene que cumplir la siguiente condición:

24

VGS > VGS(tℎ) => VGS > 4V

Se cumple que:
VGS = 12V > 4V

Además, el MOSFET IRF 530 tiene una limitación en la tensión VGS que puede soportar:

Ilustración 25. Rango de tensión entre Gate y Source

Como la etapa PPM nos entrega una tensión: 0V ≤ VGS ≤ 12V entonces se puede utilizar el MOSFET IRF 530 sin problemas.

Otra característica muy relevante del MOSFET es la potencia de disipación:

Ilustración 26. Potencia de disipación máxima

Además, la potencia también depende de la temperatura de la carcasa TC:

Ilustración 27. Multiplicador de potencia de disipación en función de Tc

Del gráfico anterior se llegan a los siguientes valores de potencia de disipación según la temperatura:

Cuando TC = 25°C => PDmax = 79W

Cuando TC = 100°C => PD = 0,5 . PDmax = 0,5 . 79W => PD = 39,5W

Corriente máxima de Drain (D):

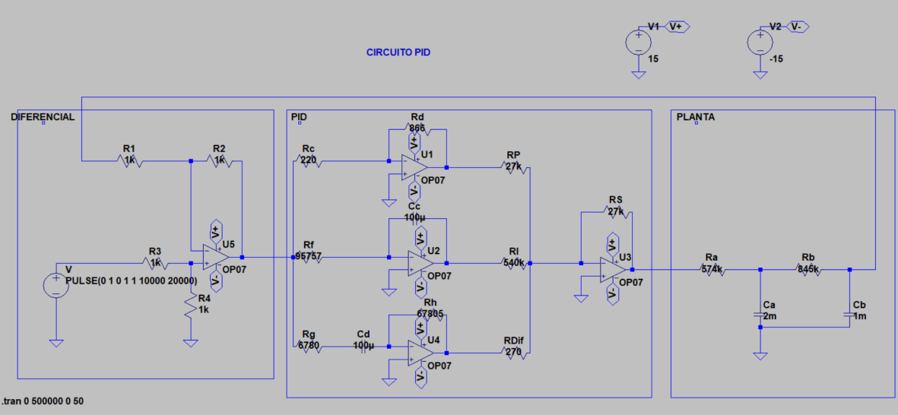
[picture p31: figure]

25

Ilustración 28. Corriente de drenaje

De la Ilustración 27 se obtiene que:

Cuando TC = 25°C => IDmax = 14A

Cuando TC = 100°C => ID = 10A

### 5. Simulación en LTSpice

Colocando los valores de los componentes calculados y hacemos una simulación en el dominio temporal para ver la respuesta del sistema, tenemos:

Ilustración 29. Circuito a simular en LTSpice

Con los siguientes datos cargados para simular:

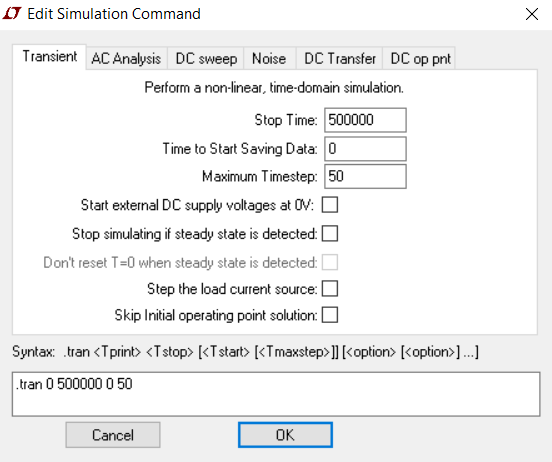
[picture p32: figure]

Ilustración 30. Características de la simulación

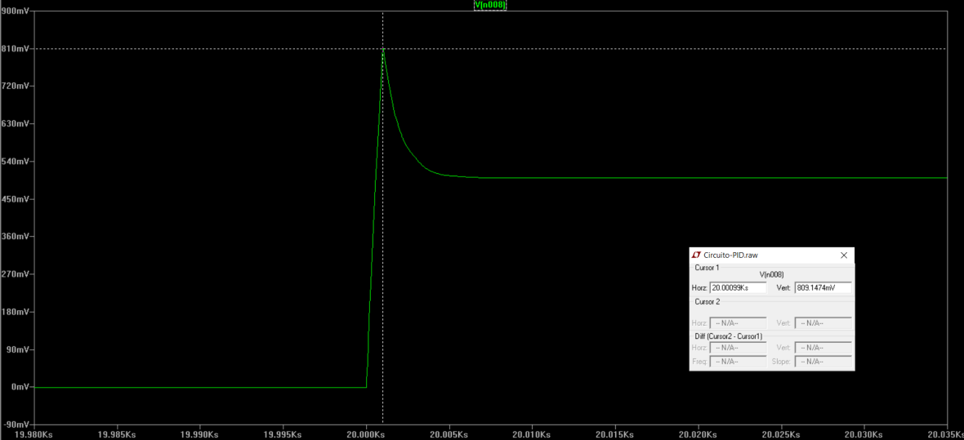
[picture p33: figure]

26

Es fundamental colocar los datos correctos en este panel para obtener una respuesta adecuada, ya que dependerán del tiempo de establecimiento del sistema para que la respuesta de la simulación sea útil.

Finalmente, si miramos la respuesta del sistema en la salida del restador entre la señal cuadrada y la respuesta del PID con controlador obtenemos:

Ilustración 31. Respuesta temporal del sistema controlado

Vemos que obtenemos el mismo resultado que obtuvimos de las simulaciones en MatLab, pero en este caso tenemos un OverShoot algo más grande que lo diseñado:

Ilustración 32. Diferencias en el OverShoot

Haciendo zoom en algún pico de la señal, vemos que tenemos un OverShoot del 60%, lo cual es bastante superior al requerido de 30%. Entendemos que esto se debe a las aproximaciones que realiza el LTSpice comparado con el MatLab y, principalmente, a la simulación de componentes reales no contemplados en el otro programa.

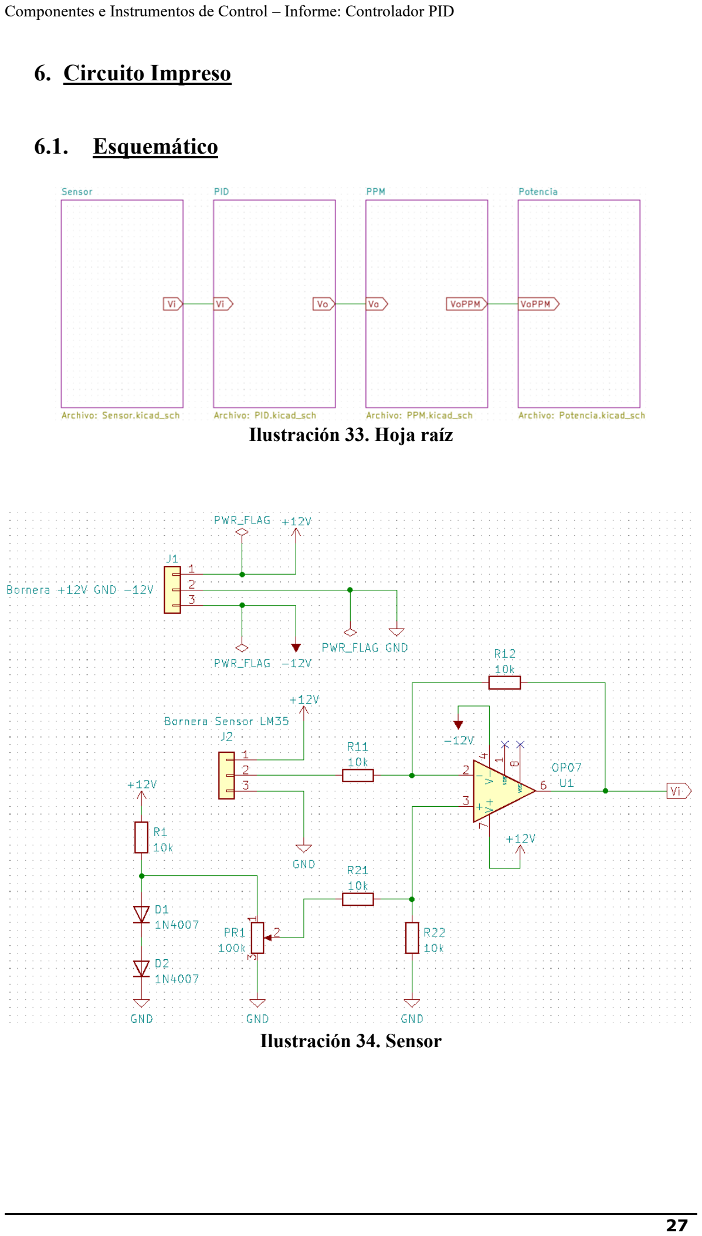
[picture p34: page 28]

27

### 6. Circuito Impreso

### 6.1. Esquemático

Ilustración 33. Hoja raíz

Ilustración 34. Sensor

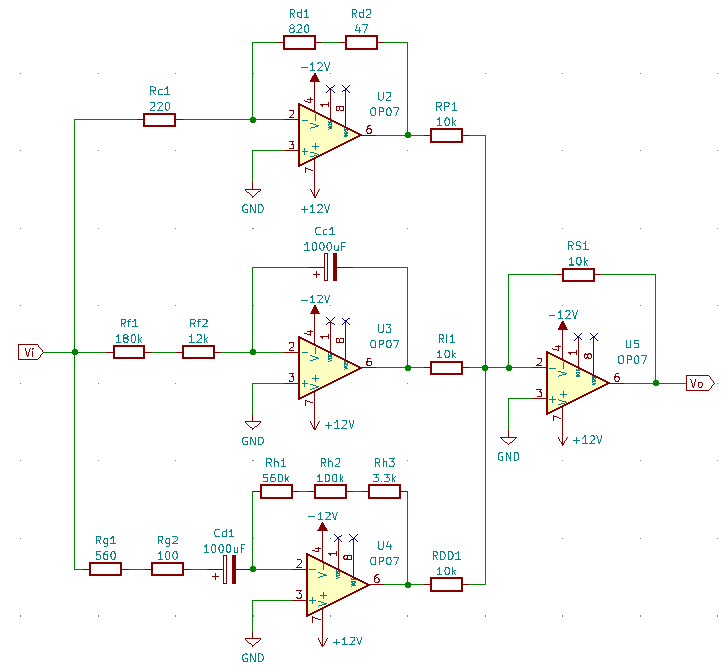
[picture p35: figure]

28

Ilustración 35. PID

29

Ilustración 36. PPM

Ilustración 37. Potencia

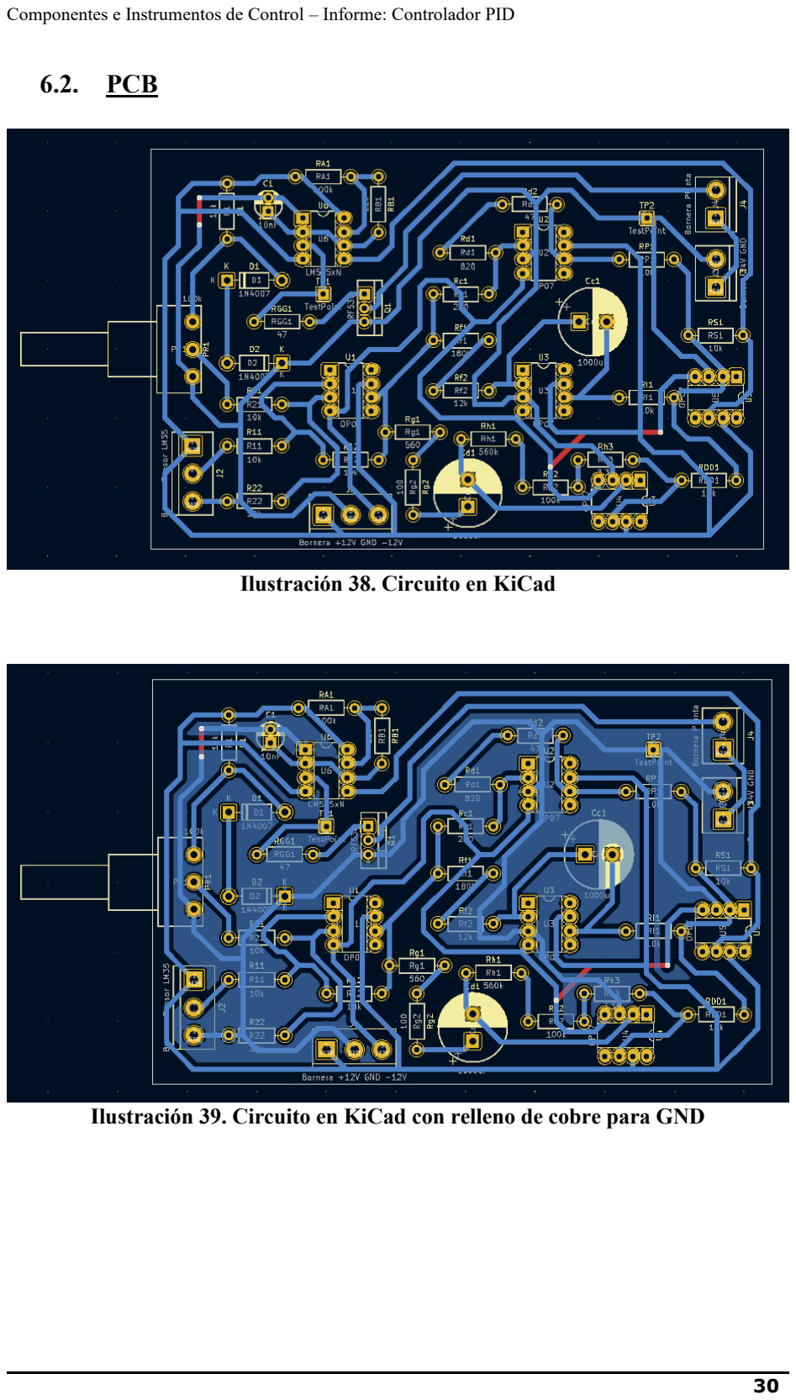
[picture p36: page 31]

30

### 6.2. PCB

Ilustración 38. Circuito en KiCad

Ilustración 39. Circuito en KiCad con relleno de cobre para GND

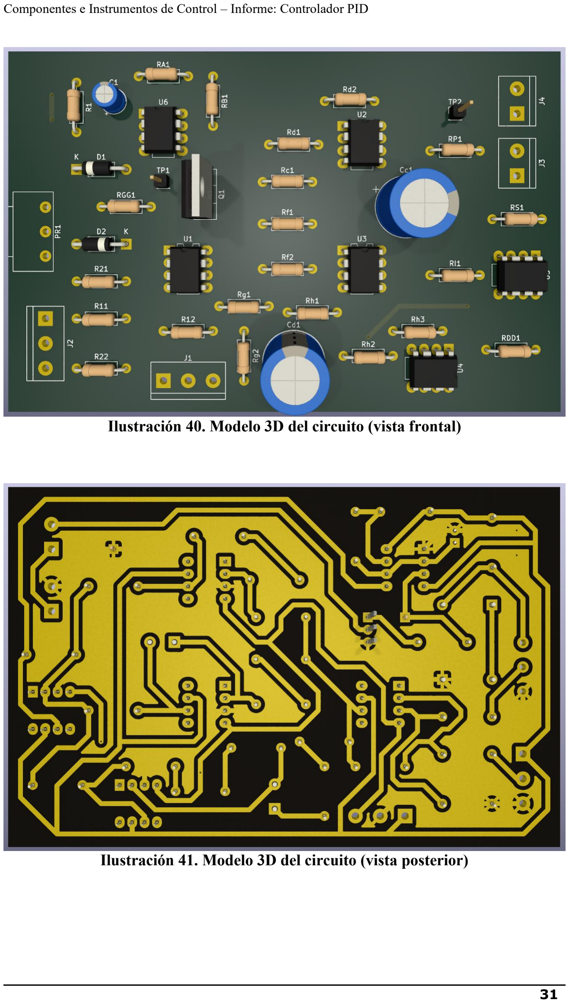
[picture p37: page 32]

31

Ilustración 40. Modelo 3D del circuito (vista frontal)

Ilustración 41. Modelo 3D del circuito (vista posterior)

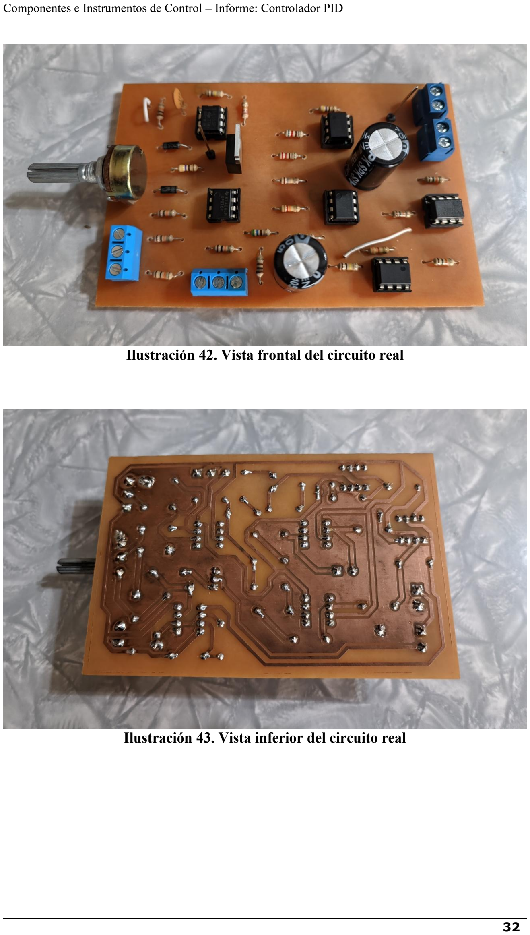
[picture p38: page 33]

32

Ilustración 42. Vista frontal del circuito real

Ilustración 43. Vista inferior del circuito real

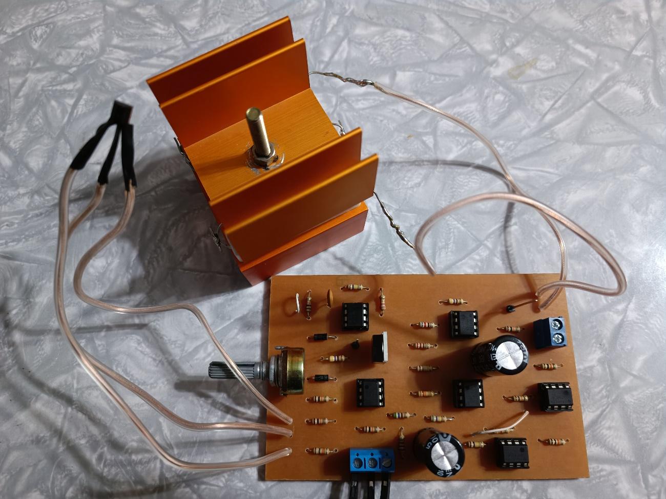
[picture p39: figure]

33

Ilustración 44. Sensor de temperatura LM35DZ, controlador PID y planta térmica

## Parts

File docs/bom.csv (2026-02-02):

Reference | Qty | Value | DNP | Exclude from BOM | Exclude from Board | Footprint | Datasheet
C1 | 1 | 10nF |  |  |  | LibraryNico:CP_Radial_D5.0mm_P2.50mm Nico | ~
Cc1,Cd1 | 2 | 1000uF |  |  |  | Capacitor_THT:CP_Radial_D12.5mm_P5.00mm | ~
D1,D2 | 2 | 1N4007 |  |  |  | Diode_THT:D_DO-41_SOD81_P10.16mm_Horizontal | ~
J1 | 1 | Bornera +12V GND -12V |  |  |  | TerminalBlock:TerminalBlock_bornier-3_P5.08mm | ~
J2 | 1 | Bornera Sensor LM35 |  |  |  | TerminalBlock:TerminalBlock_bornier-3_P5.08mm | ~
J3 | 1 | Bornera 24V GND |  |  |  | TerminalBlock:TerminalBlock_bornier-2_P5.08mm | ~
J4 | 1 | Bornera Planta |  |  |  | TerminalBlock:TerminalBlock_bornier-2_P5.08mm | ~
PR1 | 1 | 100k |  |  |  | Potentiometer_THT:Potentiometer_Piher_PC-16_Single_Horizontal | ~
Q1 | 1 | IRF530 |  |  |  | LibraryNico:TO-220-3_Vertical Nico | http://www.irf.com/product-info/datasheets/data/irf540n.pdf
R1,R11,R12,R21,R22,RDD1,RI1,RP1,RS1 | 9 | 10k |  |  |  | LibraryNico:R_Axial_DIN0207_L6.3mm_D2.5mm_P10.16mm_Horizontal Nico | ~
RA1,Rh2 | 2 | 100k |  |  |  | LibraryNico:R_Axial_DIN0207_L6.3mm_D2.5mm_P10.16mm_Horizontal Nico | ~
RB1 | 1 | 22k |  |  |  | LibraryNico:R_Axial_DIN0207_L6.3mm_D2.5mm_P10.16mm_Horizontal Nico | ~
Rc1 | 1 | 220 |  |  |  | LibraryNico:R_Axial_DIN0207_L6.3mm_D2.5mm_P10.16mm_Horizontal Nico | ~
Rd1 | 1 | 820 |  |  |  | LibraryNico:R_Axial_DIN0207_L6.3mm_D2.5mm_P10.16mm_Horizontal Nico | ~
Rd2,RGG1 | 2 | 47 |  |  |  | LibraryNico:R_Axial_DIN0207_L6.3mm_D2.5mm_P10.16mm_Horizontal Nico | ~
Rf1 | 1 | 180k |  |  |  | LibraryNico:R_Axial_DIN0207_L6.3mm_D2.5mm_P10.16mm_Horizontal Nico | ~
Rf2 | 1 | 12k |  |  |  | LibraryNico:R_Axial_DIN0207_L6.3mm_D2.5mm_P10.16mm_Horizontal Nico | ~
Rg1 | 1 | 560 |  |  |  | LibraryNico:R_Axial_DIN0207_L6.3mm_D2.5mm_P10.16mm_Horizontal Nico | ~
Rg2 | 1 | 100 |  |  |  | LibraryNico:R_Axial_DIN0207_L6.3mm_D2.5mm_P10.16mm_Horizontal Nico | ~
Rh1 | 1 | 560k |  |  |  | LibraryNico:R_Axial_DIN0207_L6.3mm_D2.5mm_P10.16mm_Horizontal Nico | ~
Rh3 | 1 | 3.3k |  |  |  | LibraryNico:R_Axial_DIN0207_L6.3mm_D2.5mm_P10.16mm_Horizontal Nico | ~
TP1,TP2 | 2 | TestPoint |  |  |  | LibraryNico:PinHeader_1x01_P2.54mm_Vertical Nico | ~
U1,U2,U3,U4,U5 | 5 | OP07 |  |  |  | LibraryNico:DIP-8_W7.62mm_LongPads Nico | https://www.analog.com/media/en/technical-documentation/data-sheets/OP07.pdf
U6 | 1 | LM555xN |  |  |  | LibraryNico:DIP-8_W7.62mm_LongPads Nico | http://www.ti.com/lit/ds/symlink/lm555.pdf

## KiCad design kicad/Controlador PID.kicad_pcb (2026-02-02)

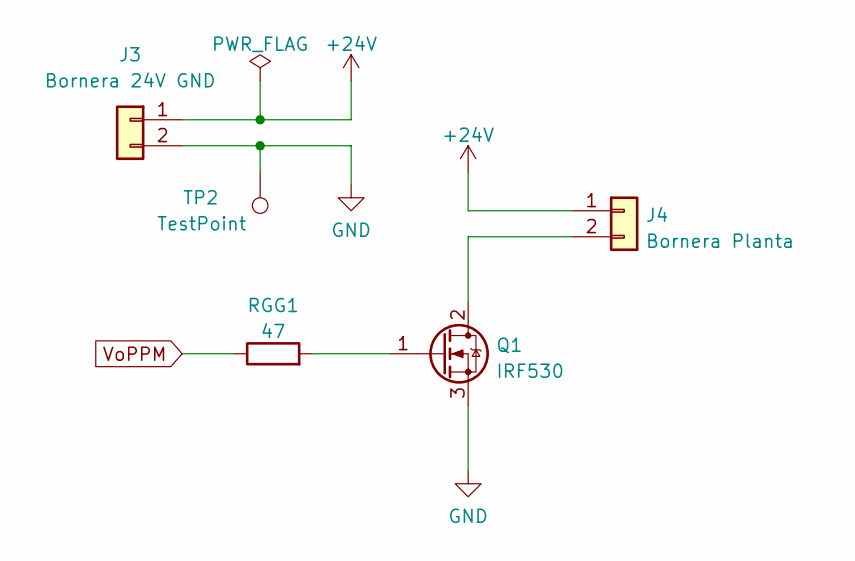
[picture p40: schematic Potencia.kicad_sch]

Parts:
J3: Bornera 24V GND; TerminalBlock_bornier-2_P5.08mm
J4: Bornera Planta; TerminalBlock_bornier-2_P5.08mm
Q1: IRF530; TO-220-3_Vertical Nico
RGG1: 47; R_Axial_DIN0207_L6.3mm_D2.5mm_P10.16mm_Horizontal Nico
TP2: TestPoint; PinHeader_1x01_P2.54mm_Vertical Nico

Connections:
+24V: J3.1, J4.1
GND: J3.2, Q1.3 (S), TP2.1; also elsewhere on the board
unnamed: J4.2, Q1.2 (D)
unnamed: Q1.1 (G), RGG1.2
VoPPM: RGG1.1; also elsewhere on the board

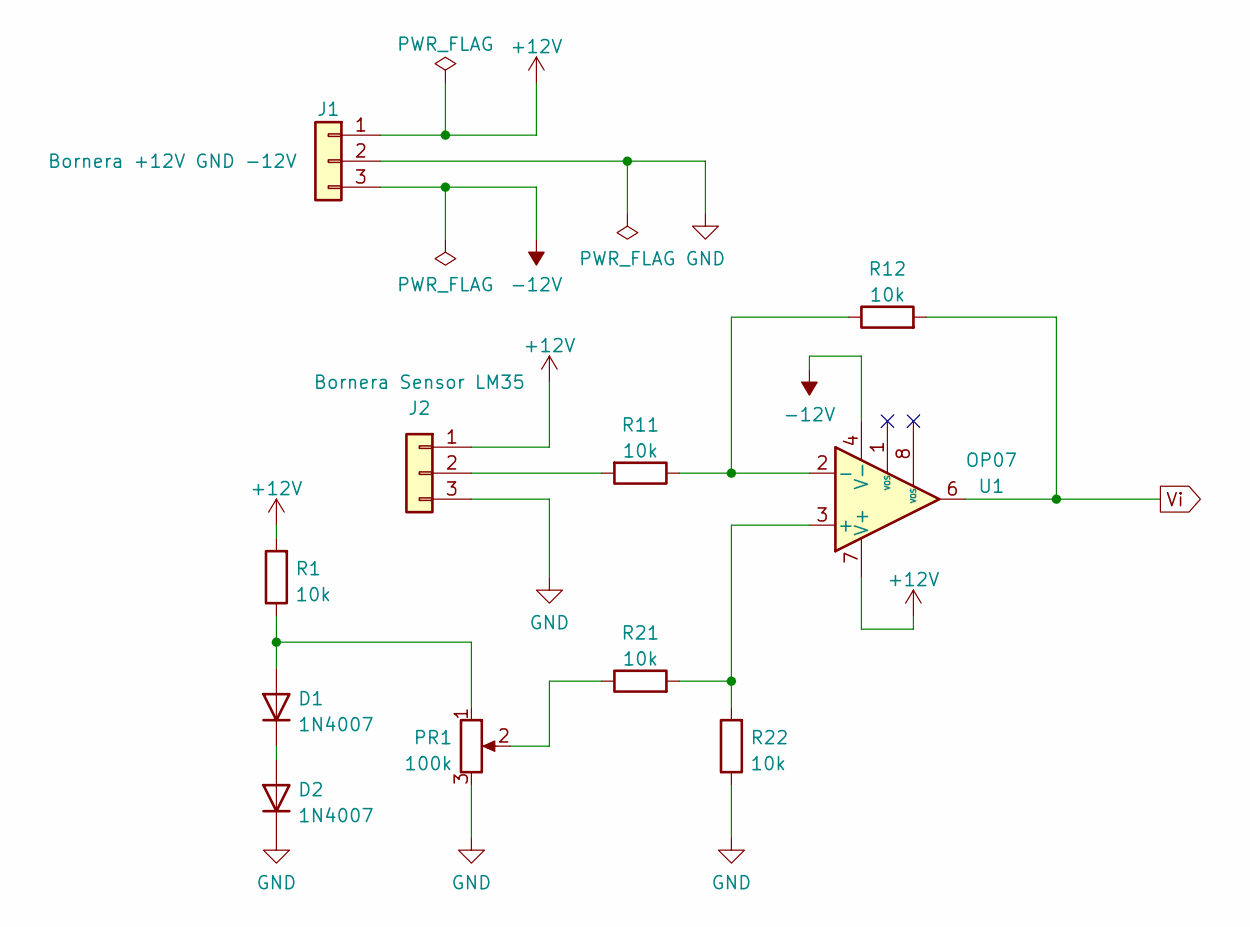
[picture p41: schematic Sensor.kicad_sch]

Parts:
D1, D2: 1N4007; D_DO-41_SOD81_P10.16mm_Horizontal
J1: Bornera +12V GND -12V; TerminalBlock_bornier-3_P5.08mm
J2: Bornera Sensor LM35; TerminalBlock_bornier-3_P5.08mm
PR1: 100k; Potentiometer_Piher_PC-16_Single_Horizontal
R1, R11, R12, R21, R22: 10k; R_Axial_DIN0207_L6.3mm_D2.5mm_P10.16mm_Horizontal Nico
U1: OP07; DIP-8_W7.62mm_LongPads Nico

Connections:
+12V: J1.1, J2.1, R1.2, U1.7 (V+); also elsewhere on the board
-12V: J1.3, U1.4 (V-); also elsewhere on the board
GND: D2.1 (K), J1.2, J2.3, PR1.3, R22.1; also elsewhere on the board
unnamed: D1.1 (K), D2.2 (A)
unnamed: D1.2 (A), PR1.1, R1.1
unnamed: J2.2, R11.2
unnamed: PR1.2, R21.1
unnamed: R11.1, R12.1, U1.2 (-)
unnamed: R21.2, R22.2, U1.3 (+)
Vi: R12.2, U1.6; also elsewhere on the board

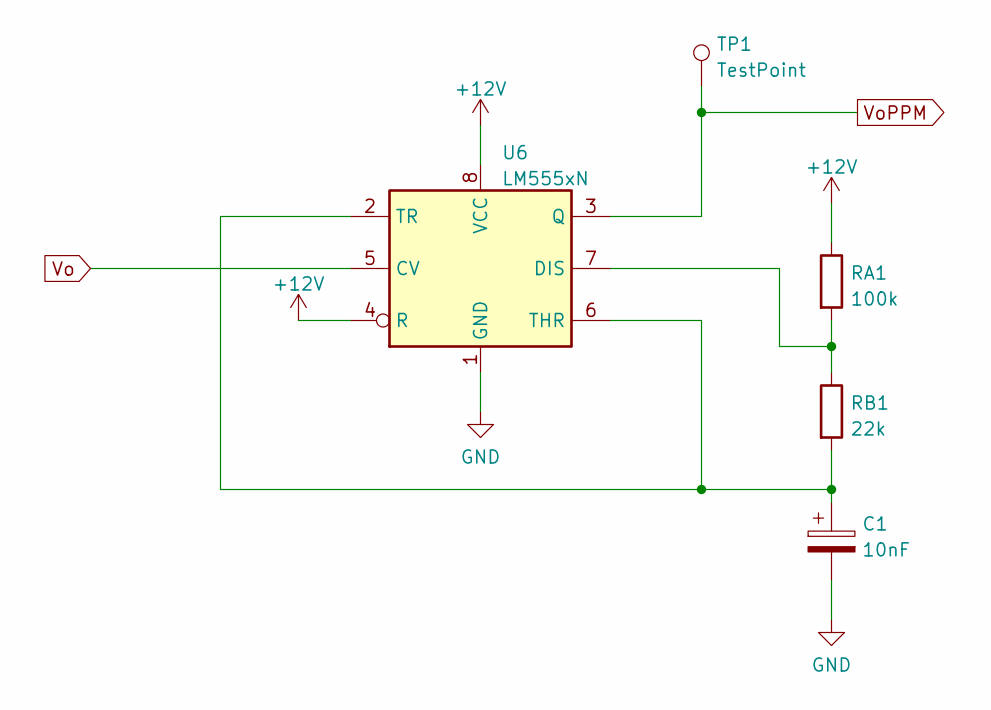
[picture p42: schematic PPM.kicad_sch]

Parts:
C1: 10nF; CP_Radial_D5.0mm_P2.50mm Nico
RA1: 100k; R_Axial_DIN0207_L6.3mm_D2.5mm_P10.16mm_Horizontal Nico
RB1: 22k; R_Axial_DIN0207_L6.3mm_D2.5mm_P10.16mm_Horizontal Nico
TP1: TestPoint; PinHeader_1x01_P2.54mm_Vertical Nico
U6: LM555xN; DIP-8_W7.62mm_LongPads Nico

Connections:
+12V: RA1.1, U6.4 (R), U6.8 (VCC); also elsewhere on the board
GND: C1.2, U6.1 (GND); also elsewhere on the board
unnamed: C1.1, RB1.2, U6.2 (TR), U6.6 (THR)
unnamed: RA1.2, RB1.1, U6.7 (DIS)
Vo: U6.5 (CV); also elsewhere on the board
VoPPM: TP1.1, U6.3 (Q); also elsewhere on the board

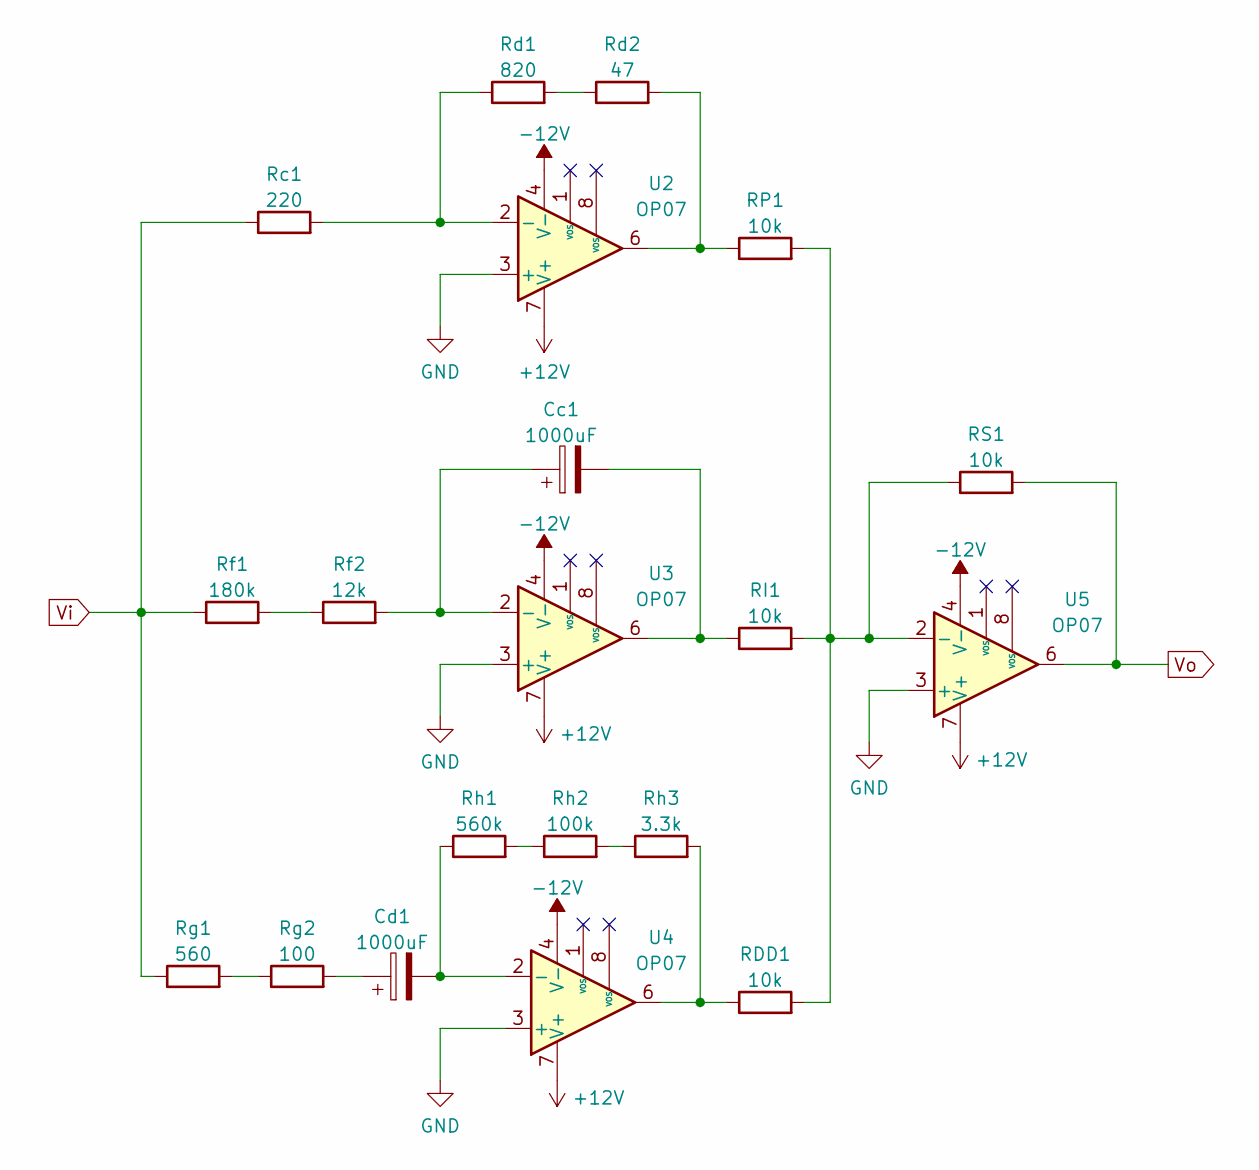
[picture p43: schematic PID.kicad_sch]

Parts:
Cc1: 1000uF; CP_Radial_D12.5mm_P5.00mm
Cd1: 1000uF; CP_Radial_D12.5mm_P5.00mm
RDD1: 10k; R_Axial_DIN0207_L6.3mm_D2.5mm_P10.16mm_Horizontal Nico
RI1: 10k; R_Axial_DIN0207_L6.3mm_D2.5mm_P10.16mm_Horizontal Nico
RP1: 10k; R_Axial_DIN0207_L6.3mm_D2.5mm_P10.16mm_Horizontal Nico
RS1: 10k; R_Axial_DIN0207_L6.3mm_D2.5mm_P10.16mm_Horizontal Nico
Rc1: 220; R_Axial_DIN0207_L6.3mm_D2.5mm_P10.16mm_Horizontal Nico
Rd1: 820; R_Axial_DIN0207_L6.3mm_D2.5mm_P10.16mm_Horizontal Nico
Rd2: 47; R_Axial_DIN0207_L6.3mm_D2.5mm_P10.16mm_Horizontal Nico
Rf1: 180k; R_Axial_DIN0207_L6.3mm_D2.5mm_P10.16mm_Horizontal Nico
Rf2: 12k; R_Axial_DIN0207_L6.3mm_D2.5mm_P10.16mm_Horizontal Nico
Rg1: 560; R_Axial_DIN0207_L6.3mm_D2.5mm_P10.16mm_Horizontal Nico
Rg2: 100; R_Axial_DIN0207_L6.3mm_D2.5mm_P10.16mm_Horizontal Nico
Rh1: 560k; R_Axial_DIN0207_L6.3mm_D2.5mm_P10.16mm_Horizontal Nico
Rh2: 100k; R_Axial_DIN0207_L6.3mm_D2.5mm_P10.16mm_Horizontal Nico
Rh3: 3.3k; R_Axial_DIN0207_L6.3mm_D2.5mm_P10.16mm_Horizontal Nico
U2, U3, U4, U5: OP07; DIP-8_W7.62mm_LongPads Nico

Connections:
+12V: U2.7 (V+), U3.7 (V+), U4.7 (V+), U5.7 (V+); also elsewhere on the board
-12V: U2.4 (V-), U3.4 (V-), U4.4 (V-), U5.4 (V-); also elsewhere on the board
GND: U2.3 (+), U3.3 (+), U4.3 (+), U5.3 (+); also elsewhere on the board
unnamed: Cc1.1, Rf2.2, U3.2 (-)
unnamed: Cc1.2, RI1.1, U3.6
unnamed: Cd1.1, Rg2.2
unnamed: Cd1.2, Rh1.1, U4.2 (-)
unnamed: RDD1.1, Rh3.2, U4.6
unnamed: RDD1.2, RI1.2, RP1.2, RS1.1, U5.2 (-)
unnamed: RP1.1, Rd2.2, U2.6
unnamed: Rc1.2, Rd1.1, U2.2 (-)
unnamed: Rd1.2, Rd2.1
unnamed: Rf1.2, Rf2.1
unnamed: Rg1.2, Rg2.1
unnamed: Rh1.2, Rh2.1
unnamed: Rh2.2, Rh3.1
Vi: Rc1.1, Rf1.1, Rg1.1; also elsewhere on the board
Vo: RS1.2, U5.6; also elsewhere on the board

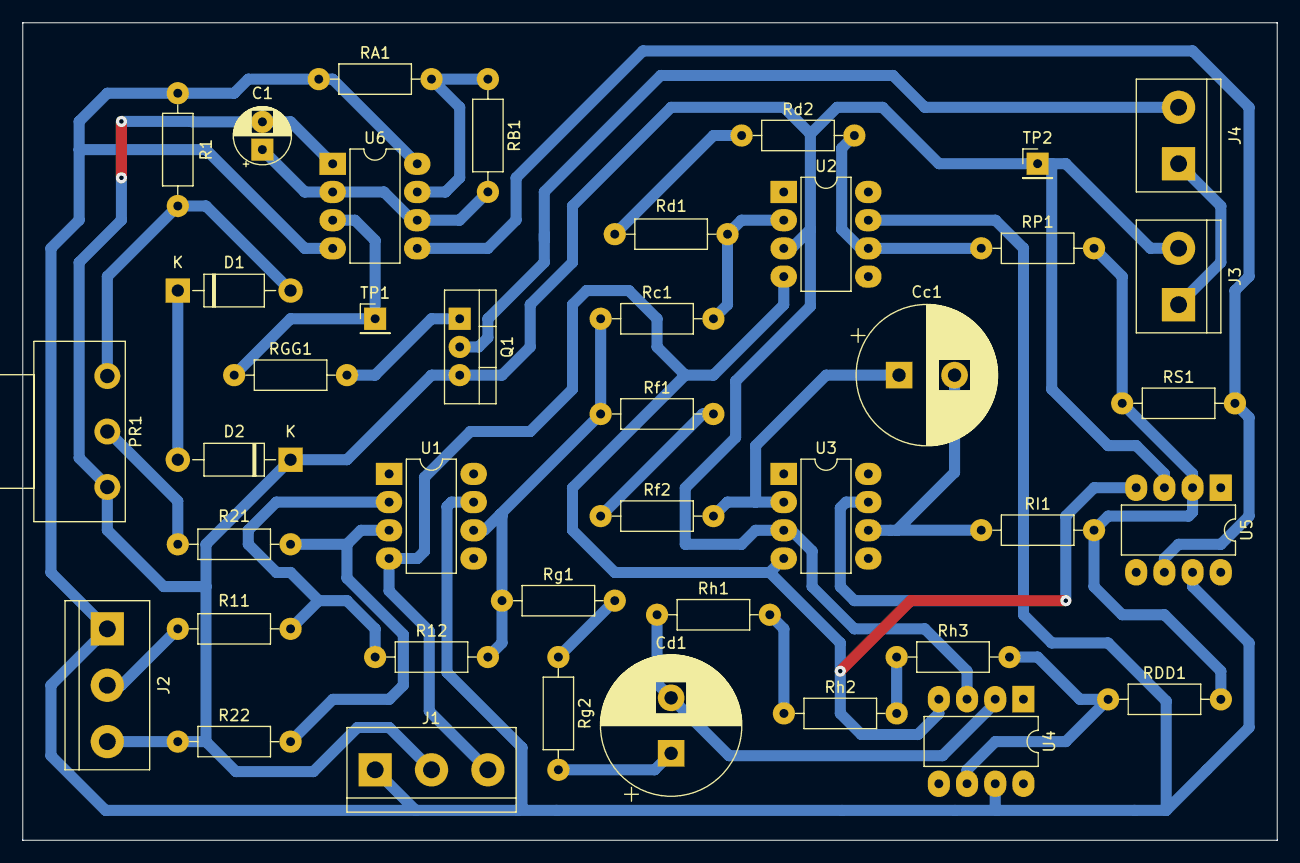
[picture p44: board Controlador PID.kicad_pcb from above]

Board: 2 copper layers, 113.0 x 73.7 mm, 41 parts (0 on the bottom side), 30 nets.

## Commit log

2026-02-02 Diseño completo y simulaciones del controlador PID
    [Controlador PID.kicad_pcb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]
2026-02-02 Fix: remover carpeta de backups mal nombrada en gitignore
